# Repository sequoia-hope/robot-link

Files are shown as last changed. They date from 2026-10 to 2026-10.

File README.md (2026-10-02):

# robot-link (comms)

### ▶ [Project page: schematic, PCB and 3D viewer](https://sequoia-hope.github.io/robot-link/)

A dev board for ST's 60 GHz contactless link: an **RP2350A** beside an
**ST60A3H1** (antenna in the package), 28 × 63 mm, six layers. Two boards
face each other a few centimetres apart and tunnel UART, GPIO, I²C or
USB 2.0 between them. The same board is either end. On the back there is a
connector for an **OV2640** camera module.

**Status: rev B captured, placed and routed. 100 parts, 83 nets; KiCad's DRC
and ERC report nothing, KiCad's own netlist of the drawn schematic matches
`tools/circuit.py` net for net, every placed part has an LCSC number and
the assembly check passes. Not fabricated, and no firmware yet.**

- **Rev A** (tag `rev-a`): the link board, four layers. Reviewed on
  2026-10-02; what the review found and changed is [below](#review).
- **Rev B**: rev A plus the [camera](#the-camera-rev-b), and six layers.

- `index.html` — status page with the board viewer (SCH, PCB, 3D); published
  from `main` at <https://sequoia-hope.github.io/robot-link/> by GitHub Pages, and
  served locally with `proj up comms`, address from `proj url comms`
- `hardware/comms/` — the KiCad project
- `tools/` — everything is generated; see below

## Why the ST60A3H1 and not the ST60A2G0

The board was asked for with the ST60A2G0. That part's ball map, pin
functions and the 60 GHz antenna and PCB-transition design are only in ST's
NDA package; the public data brief has the package outline and a block
diagram. The ST60A3H1 is the same family with a public data sheet
(DS14598) and the antenna in the package, so there is no 60 GHz copper to
design. It gives up speed: 480 Mbit/s (eUSB2) against the A2's 6.25 Gbit/s
SLVS.

## What is on it

| | |
|---|---|
| MCU | RP2350A with its core regulator, crystal, flash and decoupling as Raspberry Pi's minimal design (RP-006440) has them — the copper round the chip is read out of that board file |
| Link | ST60A3H1 on a grounded island with a copper-free ring round it, 3.5 mm in from the board edge, as on ST's X-NUCLEO-60K1A1 (B2379A) |
| Translator | TXS0108E, 1.8 V ↔ 3.3 V, on the configuration bus, the four tunnel pins, MODE_INT and LINK_STATUS; off until the RP2350 enables it. 4k7 pull-ups on the 1.8 V side of the configuration bus and of the tunnelled SCL/SDA |
| USB | PTN3222 eUSB2 repeater and two TS3USB221A switches: connector, RP2350 and the 60 GHz link, any two joined |
| Power | USB-C 5 V → AMS1117-3.3 → TLV75518P (1.8 V, off until GPIO11 goes high; dropping it is the ST60's power-on reset) |
| I/O | two 1 × 16 headers 0.9 in apart, SWD on JST-SH, BOOTSEL, RUN, power / link / user LEDs |
| Camera | on the back: a 24-way flex connector for the common OV2640 module (the ESP32-CAM's), its 2.8 V and 1.3 V regulators, pull-ups. Its signals are header GPIO |
| Mechanical | four M2.5 holes mirrored about the antenna's axis: a second board turned over on standoffs puts the two antennas on one line. Three fiducials |

GPIO map (`tools/circuit.py` has the reasons): 0–7 right-hand header · 8/9 USB
path selects · 10 RF_EN · 11 1.8 V enable · 12/13 tunnelled SDA/SCL (I2C0) ·
14 LINK_STATUS · 15 MODE_INT · 16/17 tunnelled TXD/RXD (UART0) · 18/19
configuration bus (I2C1; ST60A3H1 at 0x60, PTN3222 at 0x43) · 20 translator
enable · 21–24, 26–29 left-hand header · 25 LED.

## The camera (rev B)

For the bare OV2640 module with a 24-way, 0.5 mm flex tail: the one on the
ESP32-CAM. The connector (Hirose FH12-24S-0.5SH, bottom contact) is on the
**back** of the board. The tail goes in from the USB end with its contacts
toward the board; the module then lies on the back, behind the RP2350, with
its lens looking away from the board. That is the side away from the board
the 60 GHz link faces.

| Camera | GPIO | |
|---|---|---|
| Y2 – Y9 (data) | 0 – 7 | in order: one PIO `in pins, 8` |
| VSYNC | 21 | |
| SIOD / SIOC | 22 / 23 | I2C1, on its second pair of pins (the link's configuration bus is I2C1 on 18/19: move the peripheral, the buses do not share a wire). 4k7 pull-ups |
| PWDN | 24 | 10 k pull-up: the camera sleeps until this is driven low |
| HREF | 26 | |
| XCLK | 27 | from PWM slice 5 B, or PIO: 6 – 24 MHz, so 150 MHz ÷ 8, 10 or 12 (÷ 6 is 25 MHz, too fast). Low drive strength, slow slew: it runs beside PCLK |
| PCLK | 28 | |
| RESET | none | 10 k and 1 µF; the sensor has a software reset (COM7 bit 7), to be used once XCLK is running |

These are header pins, and with no camera plugged in they are nothing else:
26–28 are the ADC pins and have no resistor on them. 22, 23 and 24 keep
their pull-ups.

The sensor's core is on 1.3 V (OmniVision's data sheet from v1.8 on: 1.24 to
1.36 V. The older sheets, and the ESP32-CAM, say 1.2 V), its analogue side
on 2.8 V, its I/O on 3.3 V. The regulators have no enable: a fitted camera
in power-down draws 1 – 2 mA. To wake it: start XCLK, wait 10 ms, drive
PWDN low, reset it over SCCB, then configure.

The order of signals on GPIO 21–28 is not free. The camera's wiring is laid
by hand on the back, from the headers' own through-hole pads to the
connector, in one layer with nothing crossing, and only this order allows
that (`gen_board.camera_copper`).

**Checked, not tested:** which end of the connector is pin 1. The module
makers number the tail one way and the ESP32-CAM's schematic the other. The
board's pads were checked signal by signal, twice and independently, against
two module makers' mechanical drawings and Hirose's data sheet (contacts on
the face away from the lens; with the tail toward you and the contacts up,
NC and AGND on the right, Y0 and Y1 on the left). Check the module in hand
against that before plugging it in: a variant with a mirrored tail would be
the one way this is wrong.

An independent review of the camera addition (2026-10-02) confirmed the pin
order and found four things, all changed: the core supply (was 1.2 V), 100 nF
on each rail at the connector and wider supply tracks, more room round XCLK
where the wiring allows it, and the module's outline on the silkscreen, which
was 2.7 mm out. Left as they are: XCLK still runs 0.125 mm from PCLK and HREF
under the connector (the pads' order puts it between them); DOVDD is 3.3 V,
the data sheet's maximum, as on the ESP32-CAM.

With the headers soldered pins-down straight into a carrier board there is
about 2.5 mm under the board, and the module is 5.5 mm tall: it needs
sockets, or the headers the other way up.

## Board rules

Six layers, JLCPCB's JLC06161H-7628 stack: F.Cu parts and signals, In1 solid
ground, In2 and In3 routed signals, In4 supplies (+3V3, with +1V8 over the
link section), B.Cu signals, the camera's wiring and its parts. The outer
prepreg is the same 0.21 mm as JLCPCB's four-layer stack, so the antenna's
ground and the USB pairs sit as they did on rev A. Routed signals are
0.125 mm track and clearance (JLCPCB's floor is 0.09), and so are the ST60's
ball escapes. The USB pairs on the back are 0.28 mm wide and 0.16 mm apart.
Vias 0.46 / 0.2 mm, all through.

Why six: rev A routed on four. With the camera's wiring and parts on the
back, the same board on four layers left two to seven nets open in each of
three attempts, the nets at the RP2350's pins that had been marginal on
rev A. On six it closes in one or two.

## Ordering and using it

- **JLCPCB Standard PCBA, not Economic**: the ST60A3H1 is a 0.4 mm BGA, and
  Economic stops at 0.5 mm. Standard wants edge rails (JLCPCB adds them) and
  fiducials (three are on the board). Ask for a 0.10 mm stencil.
- Fifteen parts are on the back (the camera's): assembly is two-sided. To
  build the board without the camera, leave the back unassembled; nothing
  on the front depends on it.
- Green solder mask: the ST60's mask openings are 0.30 mm on 0.25 mm lands,
  which leaves 0.10 mm webs between balls, JLCPCB's minimum for green.
- Four vias sit in the gap in the ST60's ball field, tented. Plugged vias
  are the safer order.
- Fit the headers **pins down**, and use **nylon** standoffs at the antenna
  end (H1, H2): metal 11 mm from the patch is inside its beam.
- Firmware: +1V8 is off at reset. Raise GPIO11, wait 2.25 ms, then enable
  the translator (GPIO20) and RF_EN (GPIO10). Before dropping +1V8, take
  both low first. The PTN3222 is held in reset whenever the RF link is down,
  so anything written to it has to be written again after each link-up.
- VBUS on the headers is the USB-C connector's VBUS, direct: it is an
  output. Do not feed 5 V into it with a host plugged in.
- Pull-ups added on J2/J3 (the 3.3 V side of the translator) should be
  8k2 or more.

## The tools

```
python3 tools/circuit.py        # the netlist, as data, and its checks
python3 tools/symbols.py        # hardware/parts/comms.kicad_sym
python3 tools/footprints.py     # hardware/parts/comms.pretty
python3 tools/placement.py      # where every part sits, and its checks
python3 tools/gen_board.py --force   # project, schematic and the unrouted board (DISCARDS routing)
python3 tools/route.py          # freerouting on a stripped copy, results copied back, stitching
python3 tools/schdraw.py --check     # KiCad's netlist of the schematic against circuit.py
python3 tools/assembly.py       # IPC-2581, the pin-1 answers beside it, boardvis's check
python3 tools/regen.py          # every check, then the viewer and the status line on index.html
```

`gen_board.py` lays the copper that is decided rather than routed: Raspberry
Pi's tracks and pours round the RP2350, the ST60's ball field and antenna
ground (ST's own via pattern, hole for hole where it fits), the 480 Mbit/s
USB pair, a via beside every pad on a plane net,
the camera's wiring.
`route.py` hands the remaining ~70 signals to freerouting 2.2.4
(`~/Software/magnet/route`); it is not deterministic, so it makes several
attempts and keeps the first that closes everything.

## Review

Two independent passes on 2026-10-02, one over the schematic against the
data sheets and one over the layout against JLCPCB's limits and ST's
reference board. Neither found anything that would stop the board working.
What they found, and what was done:

| Finding | Done |
|---|---|
| The antenna ground was a quarter of ST's: 13 vias in the island and 15 round it, where B2379A has 53 and 56; the signals crossed the island on a diagonal | The ball field is laid as ST lays it: nine signals straight out through one side of the ring, the supply along the top of them. ST's vias are taken from its drill file: 33 fit in the island and 45 round it |
| +1V8 fall time marginal against the ST60's 1 ms limit (3.3 µF on a 120 Ω discharge) | 1.8 µF on the rail; the regulator's enable is pulled down, so the rail only rises with 3V3 settled |
| MODE_INT strap undefined if +1V8 is cycled with the translator on | 4k7 to ground on MODE_INT |
| No pull-ups on the I²C lines; ST60 and PTN3222 both want external ones | 4k7 to +1V8 on the configuration bus and on GPIO[2]/[3] |
| USB pair geometry computed at 100 Ω; it crossed two plane splits and ran 2.4 mm over no plane | 0.28 / 0.16 mm (89 Ω by the reviewer's field solver); +1V8 plane redrawn so the pair has +3V3 under it throughout; its copper now 0.8 mm from the board edge, not 0.57 |
| Solder-mask webs between balls 0.075 mm | Mask opening 0.30 mm, webs 0.10 mm |
| Silkscreen under JLCPCB's 1.0 mm / 0.15 mm | Back labels 1.0 mm, front 0.8 mm (what fits a 2.54 mm pitch), all lines 0.15 mm |
| VBUS ran under the USB-C shell | Joined on the back |
| LEDs near dark at 1 kΩ (Vf 3.1 V) | 220 Ω |
| No fiducials | Three |
| Four 3V3 capacitors at the RP2350 fed only through the ring under the chip; one via pair into the plane at the regulator | A via beside each of the four capacitors; five more at the regulator's tab |

Left as it is, knowingly:

- **TXS0108E on the I²C lines.** The reviewer would rather have a pass-FET
  translator with no edge accelerators there: the ST60 has no glitch filter
  on CFG_SCL. ST's own board uses an auto-direction part (ST2378E) on the
  same lines; that part's data sheet was not read. If the configuration bus
  misbehaves with wiring on J2, this is the first place to look.
- **AMS1117 with ceramic output capacitors**, as Raspberry Pi's reference has
  an 1117: outside what the AMS data sheet characterises (22 µF tantalum).
  It needs about 1 V of headroom, so VBUS has to stay above 4.35 V.
- **The crystal** is servodrive's 2520 (CL 20 pF) with 27 pF, where Raspberry
  Pi specifies an ABM8-272 with 15 pF and says any change needs testing.
- **USB pair skew**: D− is 1.1 mm longer than D+ between the connector and
  the first switch (its two pads are joined under the shell). The long run
  to the repeater is matched to 0.05 mm.
- **The ground guard round the crystal** in the reference was not copied;
  three signals pass within 0.13 mm of the crystal nets.

## Not yet verified

- Nothing has been built. The ST60A3H1 land and the PTN3222 land are drawn
  from the manufacturers' drawings, not from a part in hand.
- The antenna island copies ST's dimensions and vias off their Gerbers; the
  pattern on this board has not been simulated or measured, and it has
  fewer vias than ST's where this board's tracks are in the way.
- The 89 Ω figure for the USB pairs is one reviewer's solver, checked
  against a textbook formula only. Confirm with JLCPCB's calculator.
- JLCPCB capability figures were read off their site on 2026-10-02 through
  a summarising tool, not from the raw pages. Check them at order time.
- Several pin-1 answers in the assembly sidecar are package convention,
  not read off that part's data sheet; the sidecar says which.
- Rev B's camera connector: see "Checked, not tested" above. The camera's
  wiring runs 15 to 40 mm on the back over the supply plane; nothing about
  its signal integrity at a 20 MHz pixel clock has been measured.
- The 2.8 V regulator is listed as UMW's XC6206; its data sheet numbers the
  pins oddly, and the reviewer read it as the same physical order as Torex's.

## Next

Firmware: the link's bring-up sequence, a PIO capture for the camera. Then
a first build.

CERN-OHL-P.

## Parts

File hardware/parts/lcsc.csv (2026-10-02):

# LCSC part numbers the project has chosen | keyed by value and footprint as
# the board file writes them; pcbview joins this into the viewer's part pane.
# The C-number is the same at LCSC and JLCPCB.
#
# Every part the assembler places has a row. Rows marked "as servodrive" are
# that project's choices for the same value and footprint; the rest were
# looked up in JLCPCB's parts library on 2026-10-02 (model | package | stock).
# The mounting holes have no part.
value | footprint | lcsc | mpn | note
RP2350A | RP2350-QFN-60-1EP_7x7_P0.4mm_EP3.4x3.4mm_ThermalVias | C42411118 | RP2350A | as servodrive
3u3 | L_pol_2016 | C42411119 | AOTA-B201610S3R3-101-T | as servodrive
4u7 | C_0402_1005Metric_small_pads | C23733 | CL05A475MP5NRNC | as servodrive
4u7 | C_0402_1005Metric | C23733 | CL05A475MP5NRNC | as servodrive
33R | R_0402_1005Metric | C25105 | 0402WGF330JTCE | as servodrive
100n | C_0402_1005Metric | C1525 | CL05B104KO5NNNC | as servodrive
27R | R_0402_1005Metric | C25100 | 0402WGF270JTCE | as servodrive
12MHz | Crystal_SMD_2520-4Pin_2.5x2.0mm | C284156 | TXM12M0004252LBCEO00T | as servodrive
1k | R_0402_1005Metric | C11702 | 0402WGF1001TCE | as servodrive
27p | C_0402_1005Metric | C1557 | 0402CG270J500NT | as servodrive
W25Q16JVUXIQ | Winbond_USON-8-1EP_3x2mm_P0.5mm_EP0.2x1.6mm | C2843335 | W25Q16JVUXIQ | as servodrive
BOOTSEL | SW_SPST_B3U-1000P | C231329 | B3U-1000P | as servodrive
RUN | SW_SPST_B3U-1000P | C231329 | B3U-1000P
SWD | JST_SH_SM03B-SRSS-TB_1x03-1MP_P1.00mm_Horizontal | C2845362 | HC-1.0-3PWT | SH-compatible 3-way, in stock by the reel; JST's own SM03B-SRSS-TB is C160403, 22 in stock that day
blue | LED_0603_1608Metric | C2288 | KT-0603B | Vf 3.1 V at 5 mA: on 3V3 through 1k it runs well under 1 mA, dim on purpose
LEFT | PinHeader_1x16_P2.54mm_Vertical | C22465876 | PZ254V-11-16P | through-hole; fit by hand, or leave off the assembly order
RIGHT | PinHeader_1x16_P2.54mm_Vertical | C22465876 | PZ254V-11-16P | through-hole; fit by hand, or leave off the assembly order
ST60A3H1 | ST_VFBGA-23_AiP_2.95x4.07mm_P0.4mm | C49438993 | ST60A3H1C1CCEPY3 | 36 in stock that day; 0.4 mm VFBGA, antenna in package
0R | R_0402_1005Metric | C17168 | 0402WGF0000TCE | basic
1u | C_0402_1005Metric | C52923 | CL05A105KA5NQNC | as servodrive
1k5 | R_0402_1005Metric | C25867 | 0402WGF1501TCE | basic
1k8 | R_0402_1005Metric | C25871 | 0402WGF1801TCE
TXS0108E | TSSOP-20_4.4x6.5mm_P0.65mm | C17206 | TXS0108EPWR
4k7 | R_0402_1005Metric | C25900 | 0402WGF4701TCE | as servodrive
PTN3222GM | NXP_XQFN-12_1.75x2.2mm_P0.4mm | C5364806 | PTN3222GMJ | 359 in stock that day
100p | C_0402_1005Metric | C1546 | 0402CG101J500NT | basic, C0G
MMBT3904 | SOT-23 | C20526 | MMBT3904 | basic
10k | R_0402_1005Metric | C25744 | 0402WGF1002TCE | as servodrive
green | LED_0603_1608Metric | C12624 | KT-0603G | Vf 3.1 V at 5 mA, as the blue one
USB-C | USB_C_Receptacle_HRO_TYPE-C-31-M-12 | C165948 | TYPE-C-31-M-12 | as servodrive
5k1 | R_0402_1005Metric | C25905 | 0402WGF5101TCE | as servodrive
USBLC6-2SC6 | SOT-23-6 | C7519 | USBLC6-2SC6 | as servodrive
TS3USB221A | Texas_UQFN-10_1.5x2mm_P0.5mm | C128396 | TS3USB221ARSER
AMS1117-3.3 | SOT-223-3_TabPin2 | C6186 | AMS1117-3.3 | basic
10u | C_0805_2012Metric | C15850 | CL21A106KAYNNNE | basic, 25 V X5R
TLV75518P | SOT-23-5 | C2877863 | TLV75518PDBVR | the P is the output discharge
220R | R_0402_1005Metric | C25091 | 0402WGF2200TCE | basic; the LEDs' series resistors
470n | C_0402_1005Metric | C92361 | CL05A474KA5NNNC | 25 V X5R
OV2640 | Hirose_FH12-24S-0.5SH_1x24-1MP_P0.50mm_Horizontal | C202112 | FH12-24S-0.5SH(55) | 24-way 0.5 mm flex connector, bottom contact; on the back
XC6206P282MR | SOT-23 | C347374 | XC6206P282MR | 2.8 V LDO (UMW's; Torex's own is C2891263)
ME6216A13M3G | SOT-23 | C236662 | ME6216A13M3G | 1.3 V LDO, 300 mA; SOT23-3 pin order as the XC6206 (1 VSS, 2 VOUT, 3 VIN), read off Microne's data sheet

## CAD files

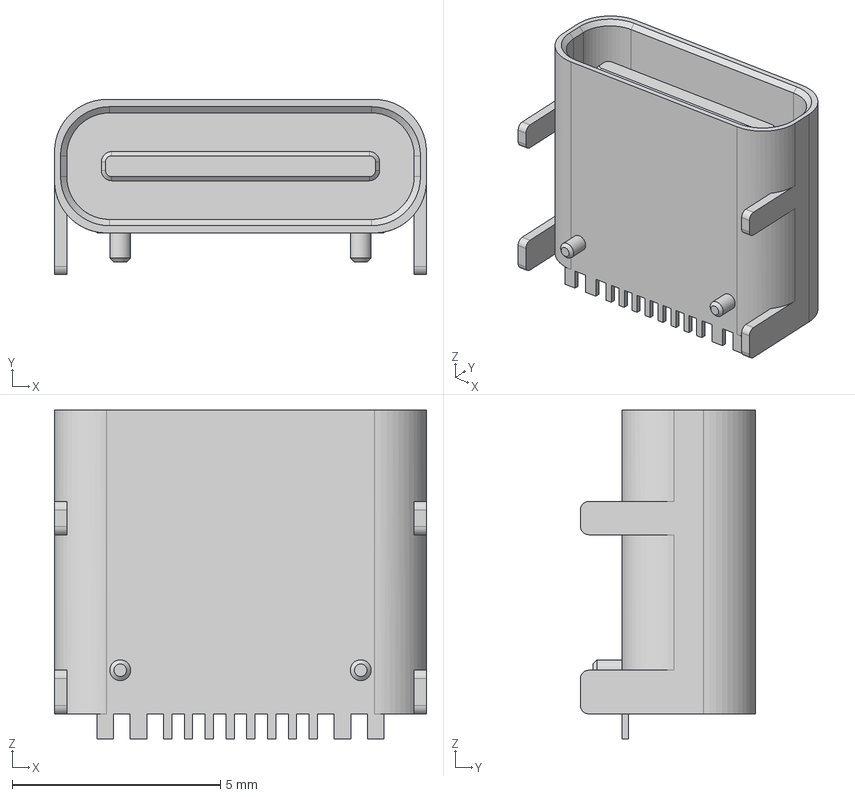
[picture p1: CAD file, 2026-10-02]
hardware/parts/3dmodels/HRO_TYPE-C-31-M-12.step
8.94 x 4.21 x 7.90 mm

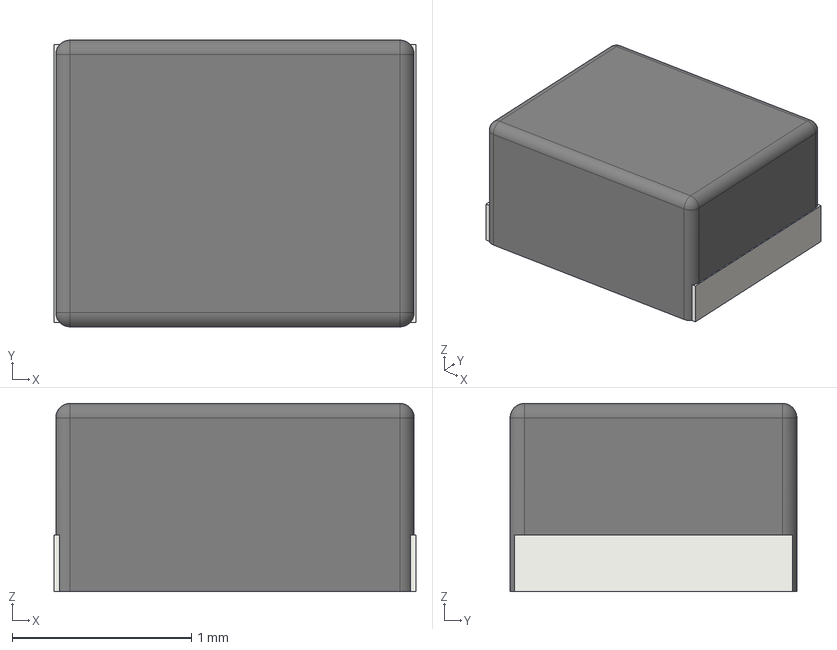
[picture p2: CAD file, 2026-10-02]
hardware/parts/3dmodels/AOTA-B201610SR47MT.STEP
2.02 x 1.60 x 1.05 mm

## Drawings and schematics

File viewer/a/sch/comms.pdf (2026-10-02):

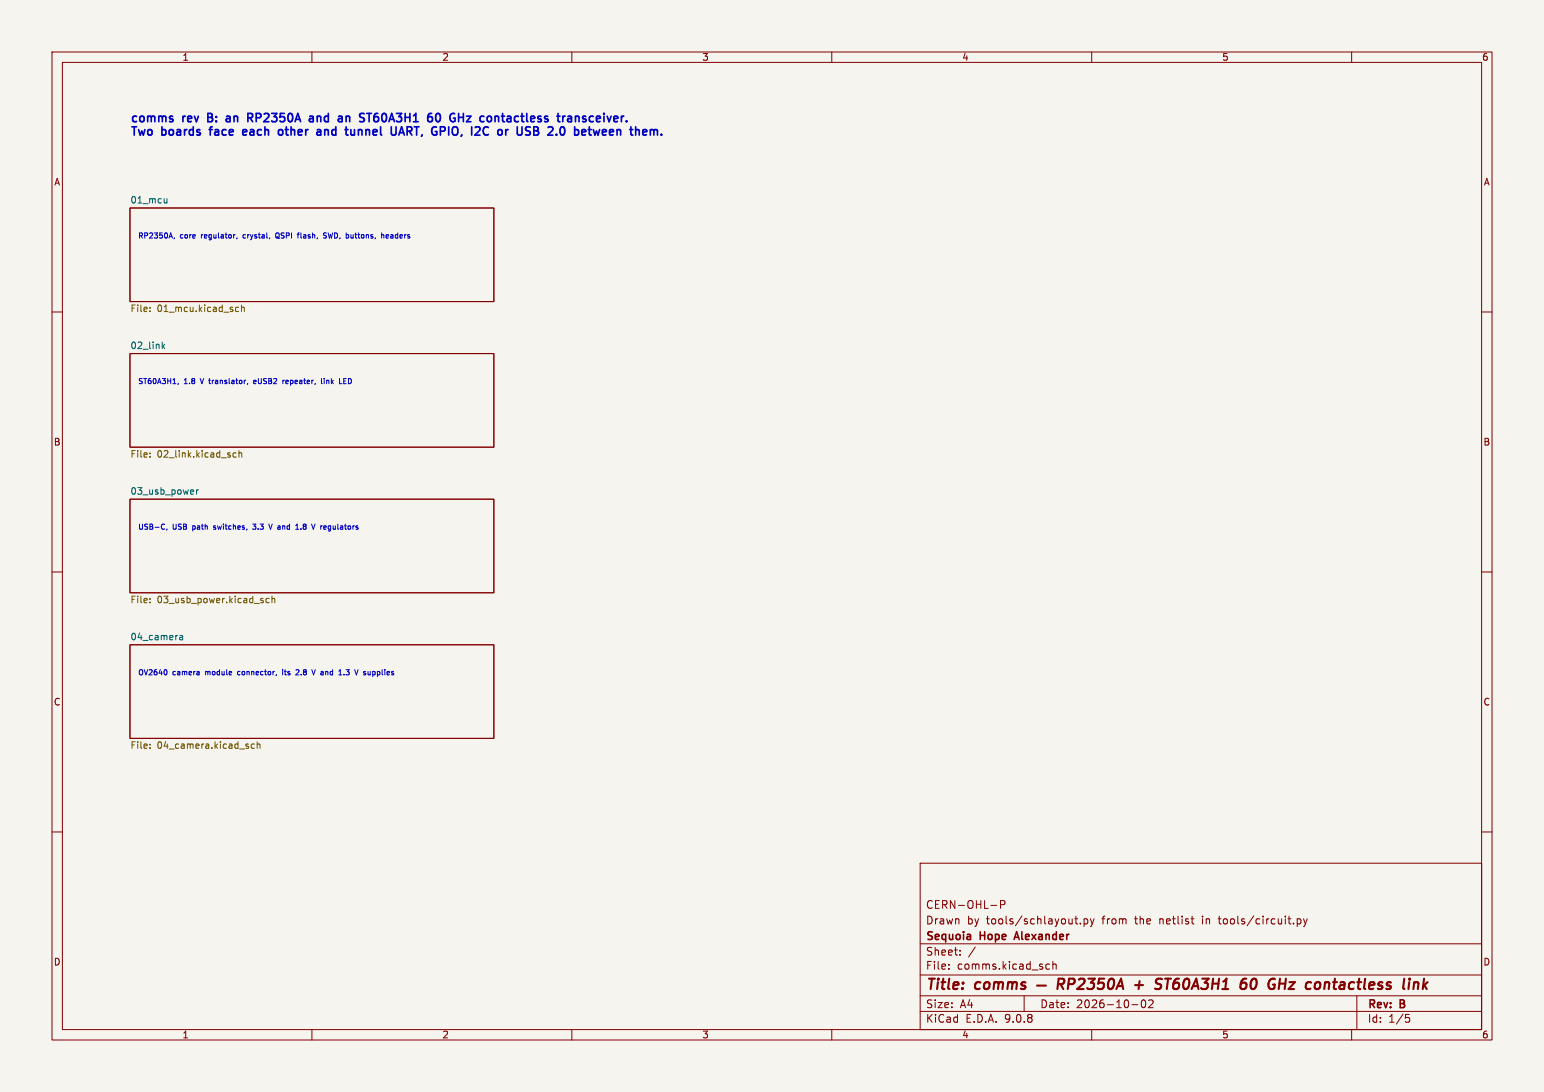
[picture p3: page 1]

Two boards face each other and tunnel UART, GPIO, I2C or USB 2.0 between them.

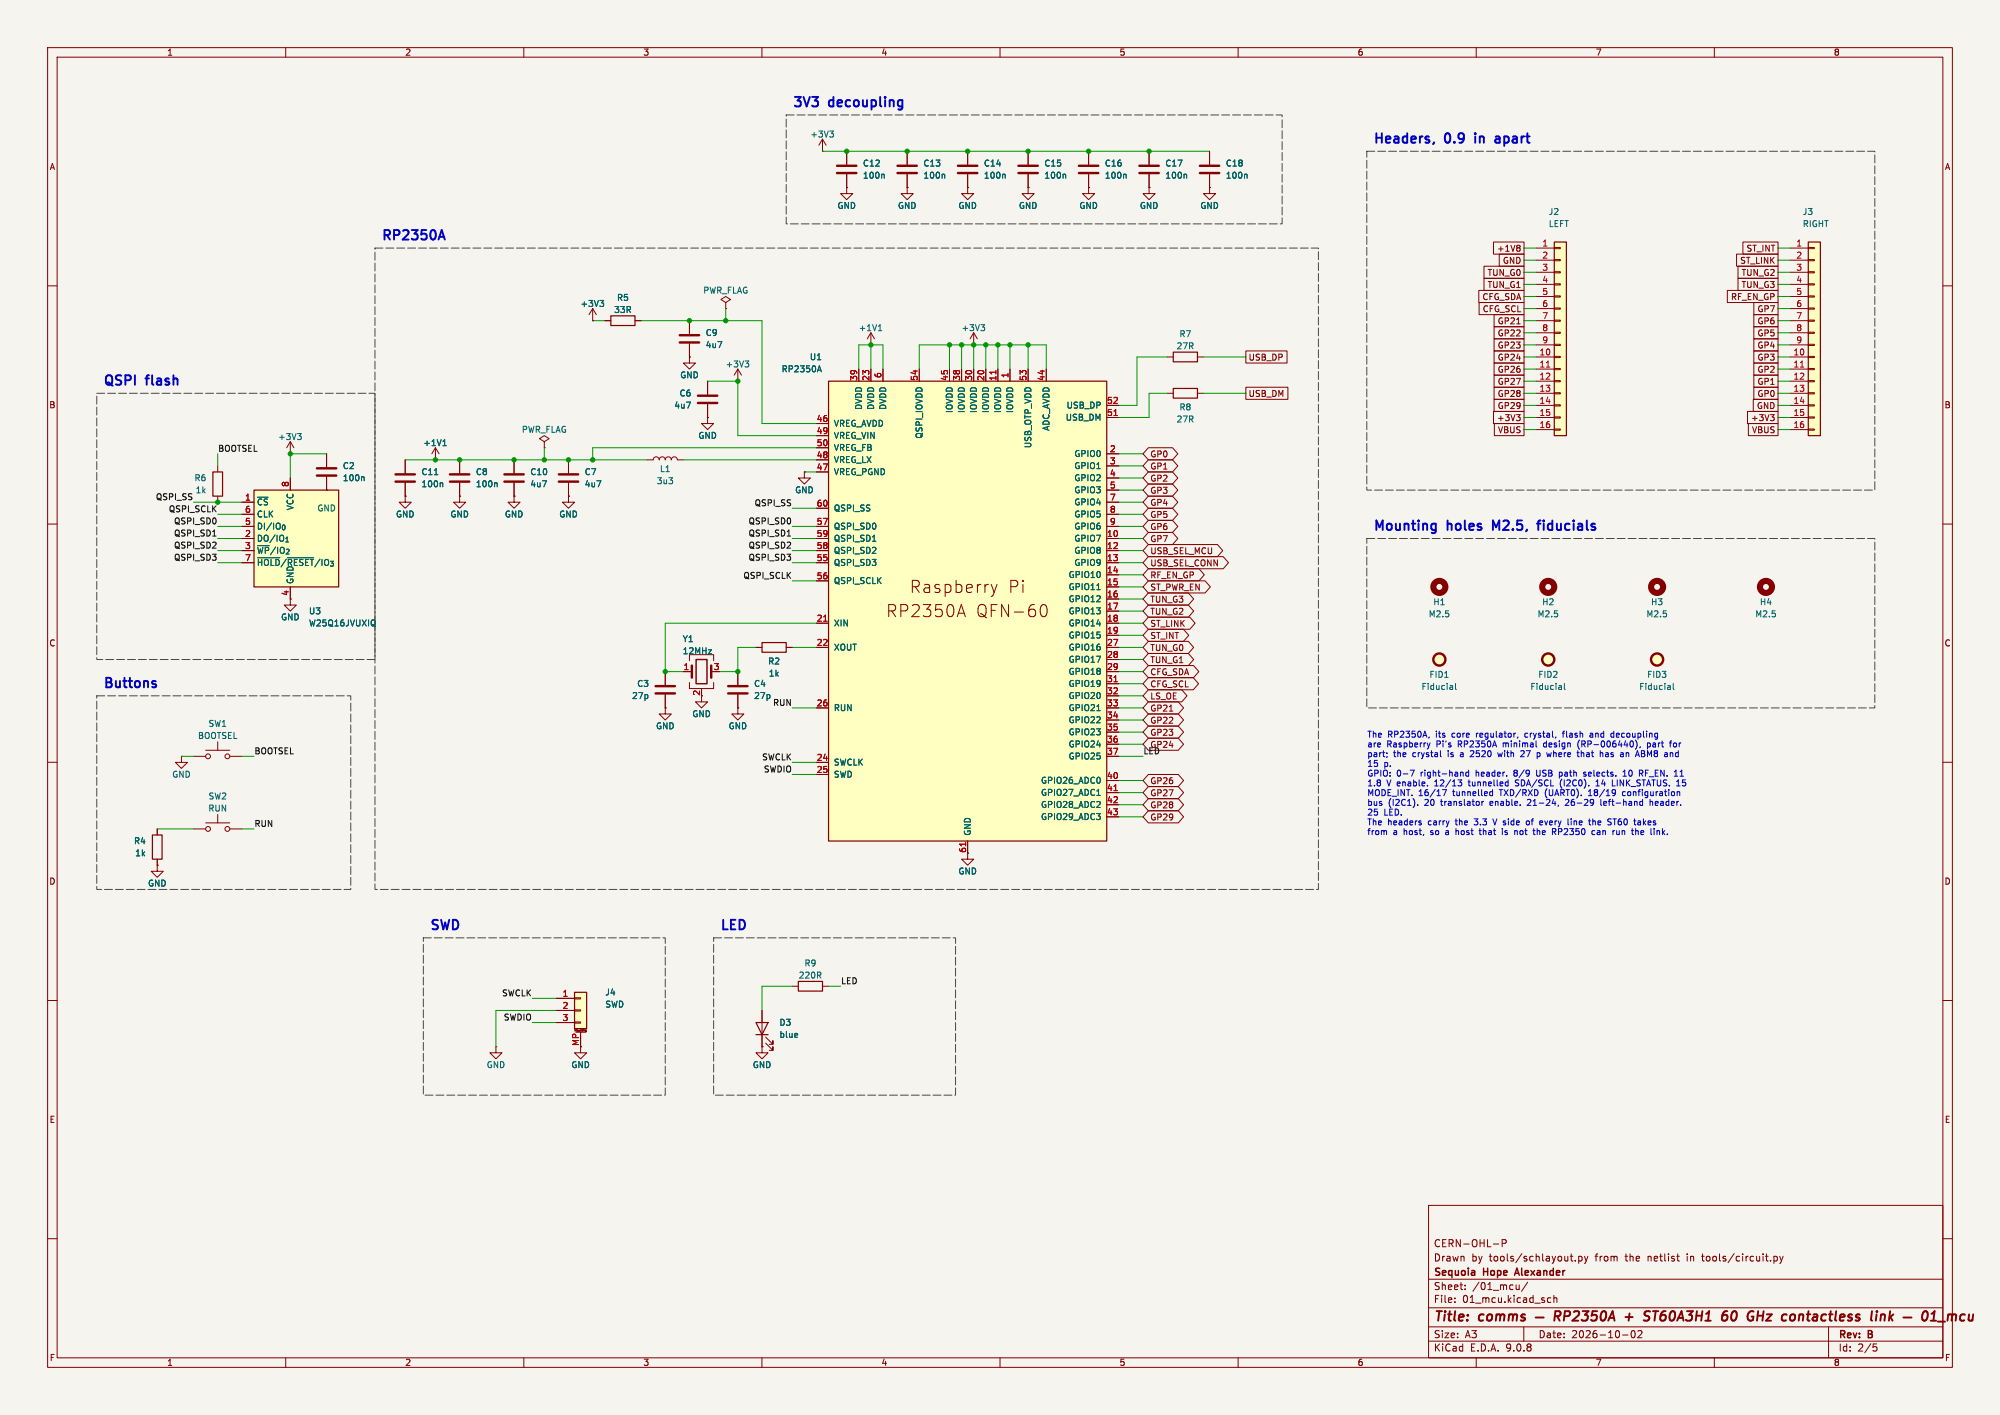
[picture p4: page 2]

6 QSPI_IOVDD 54 IOVDD 45 IOVDD 38 GND 61 IOVDD 30 IOVDD 20 IOVDD 11 IOVDD

from a host, so a host that is not the RP2350 can run the link.

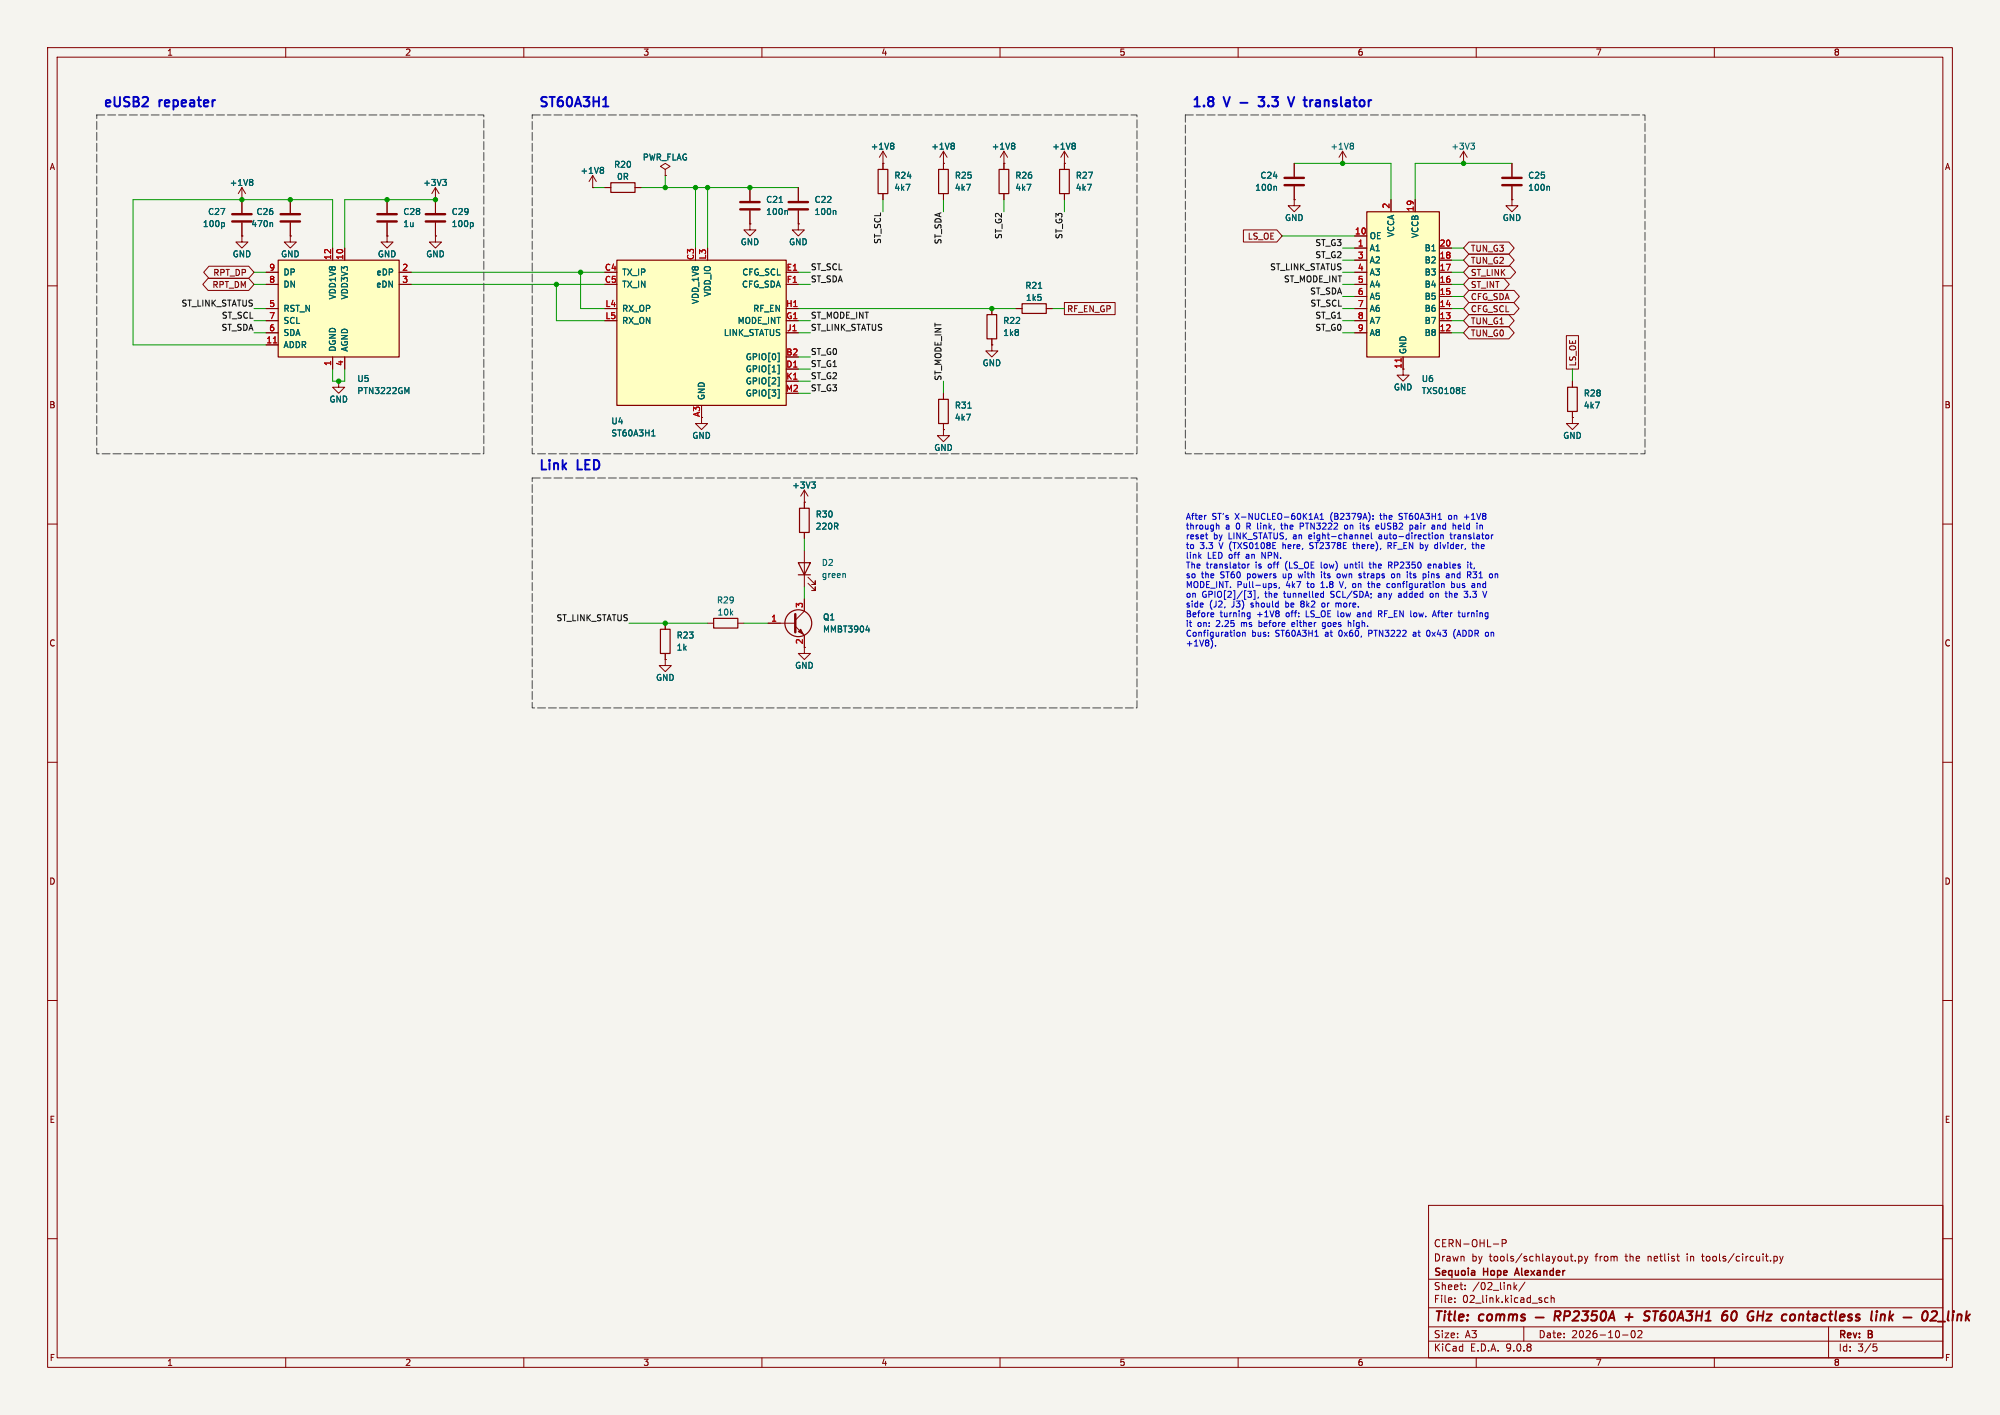
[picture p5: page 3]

LINK_STATUS J1 GPIO[0] B2 GPIO[1] D1 GPIO[2] K1 GPIO[3] M2 C21

2 GND 11 VCCB 19 B1 20 B2 18 B3 17 B4 16 B5 15 B6 14 B7 13 B8 12 U6 TXS0108E GND GND

through a 0 R link, the PTN3222 on its eUSB2 pair and held in
to 3.3 V (TXS0108E here, ST2378E there), RF_EN by divider, the

side (J2, J3) should be 8k2 or more. Before turning +1V8 off: LS_OE low and RF_EN low. After turning

it on: 2.25 ms before either goes high.

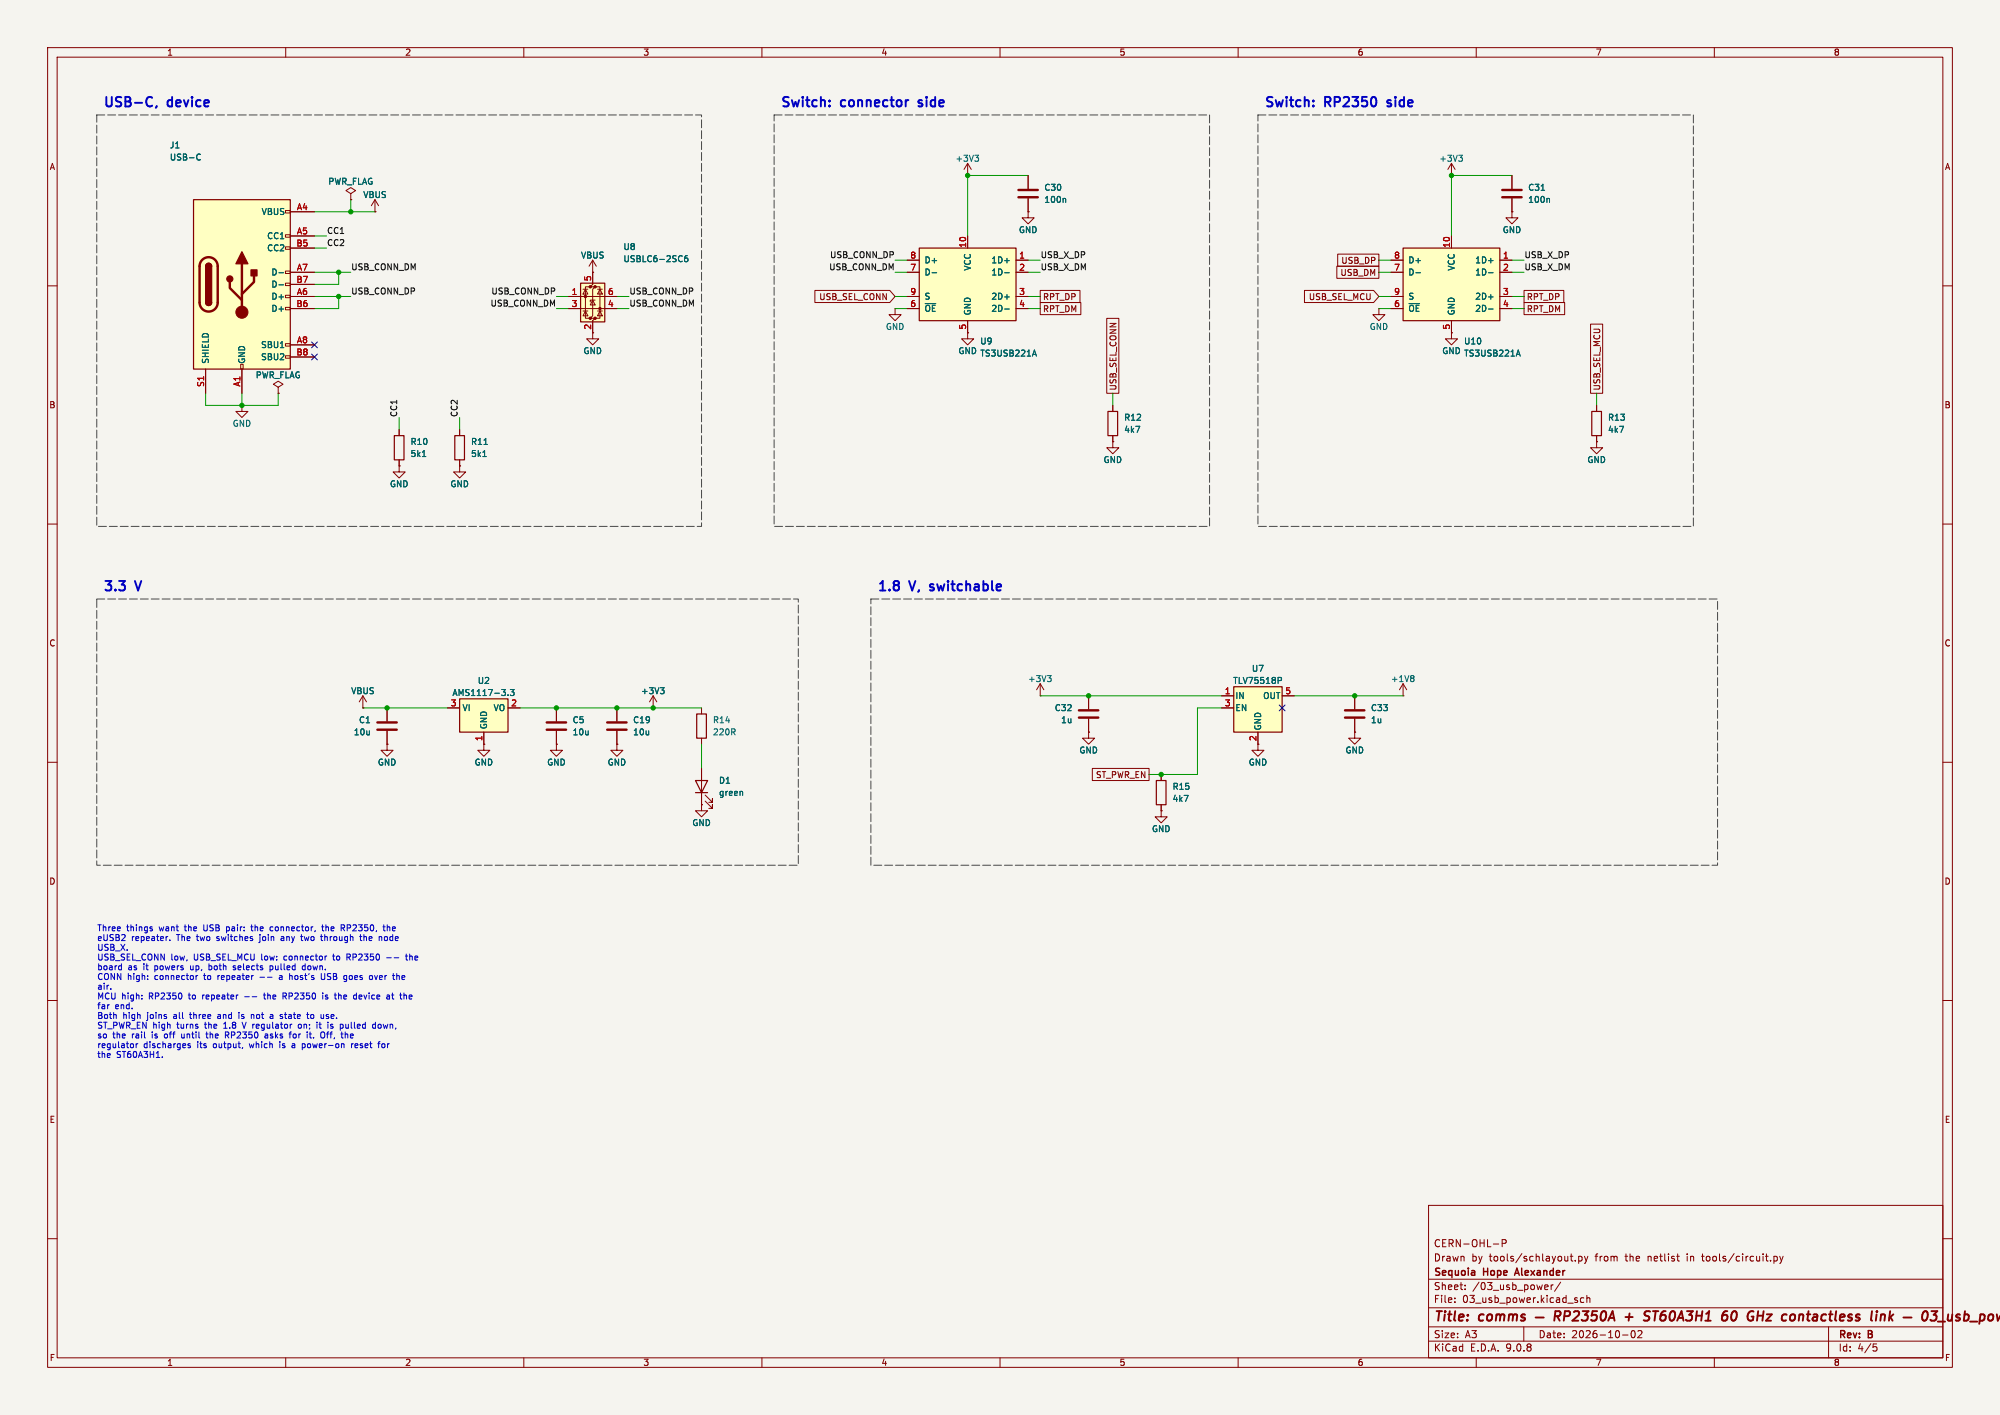
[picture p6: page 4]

2 OUT 5 GND GND GND

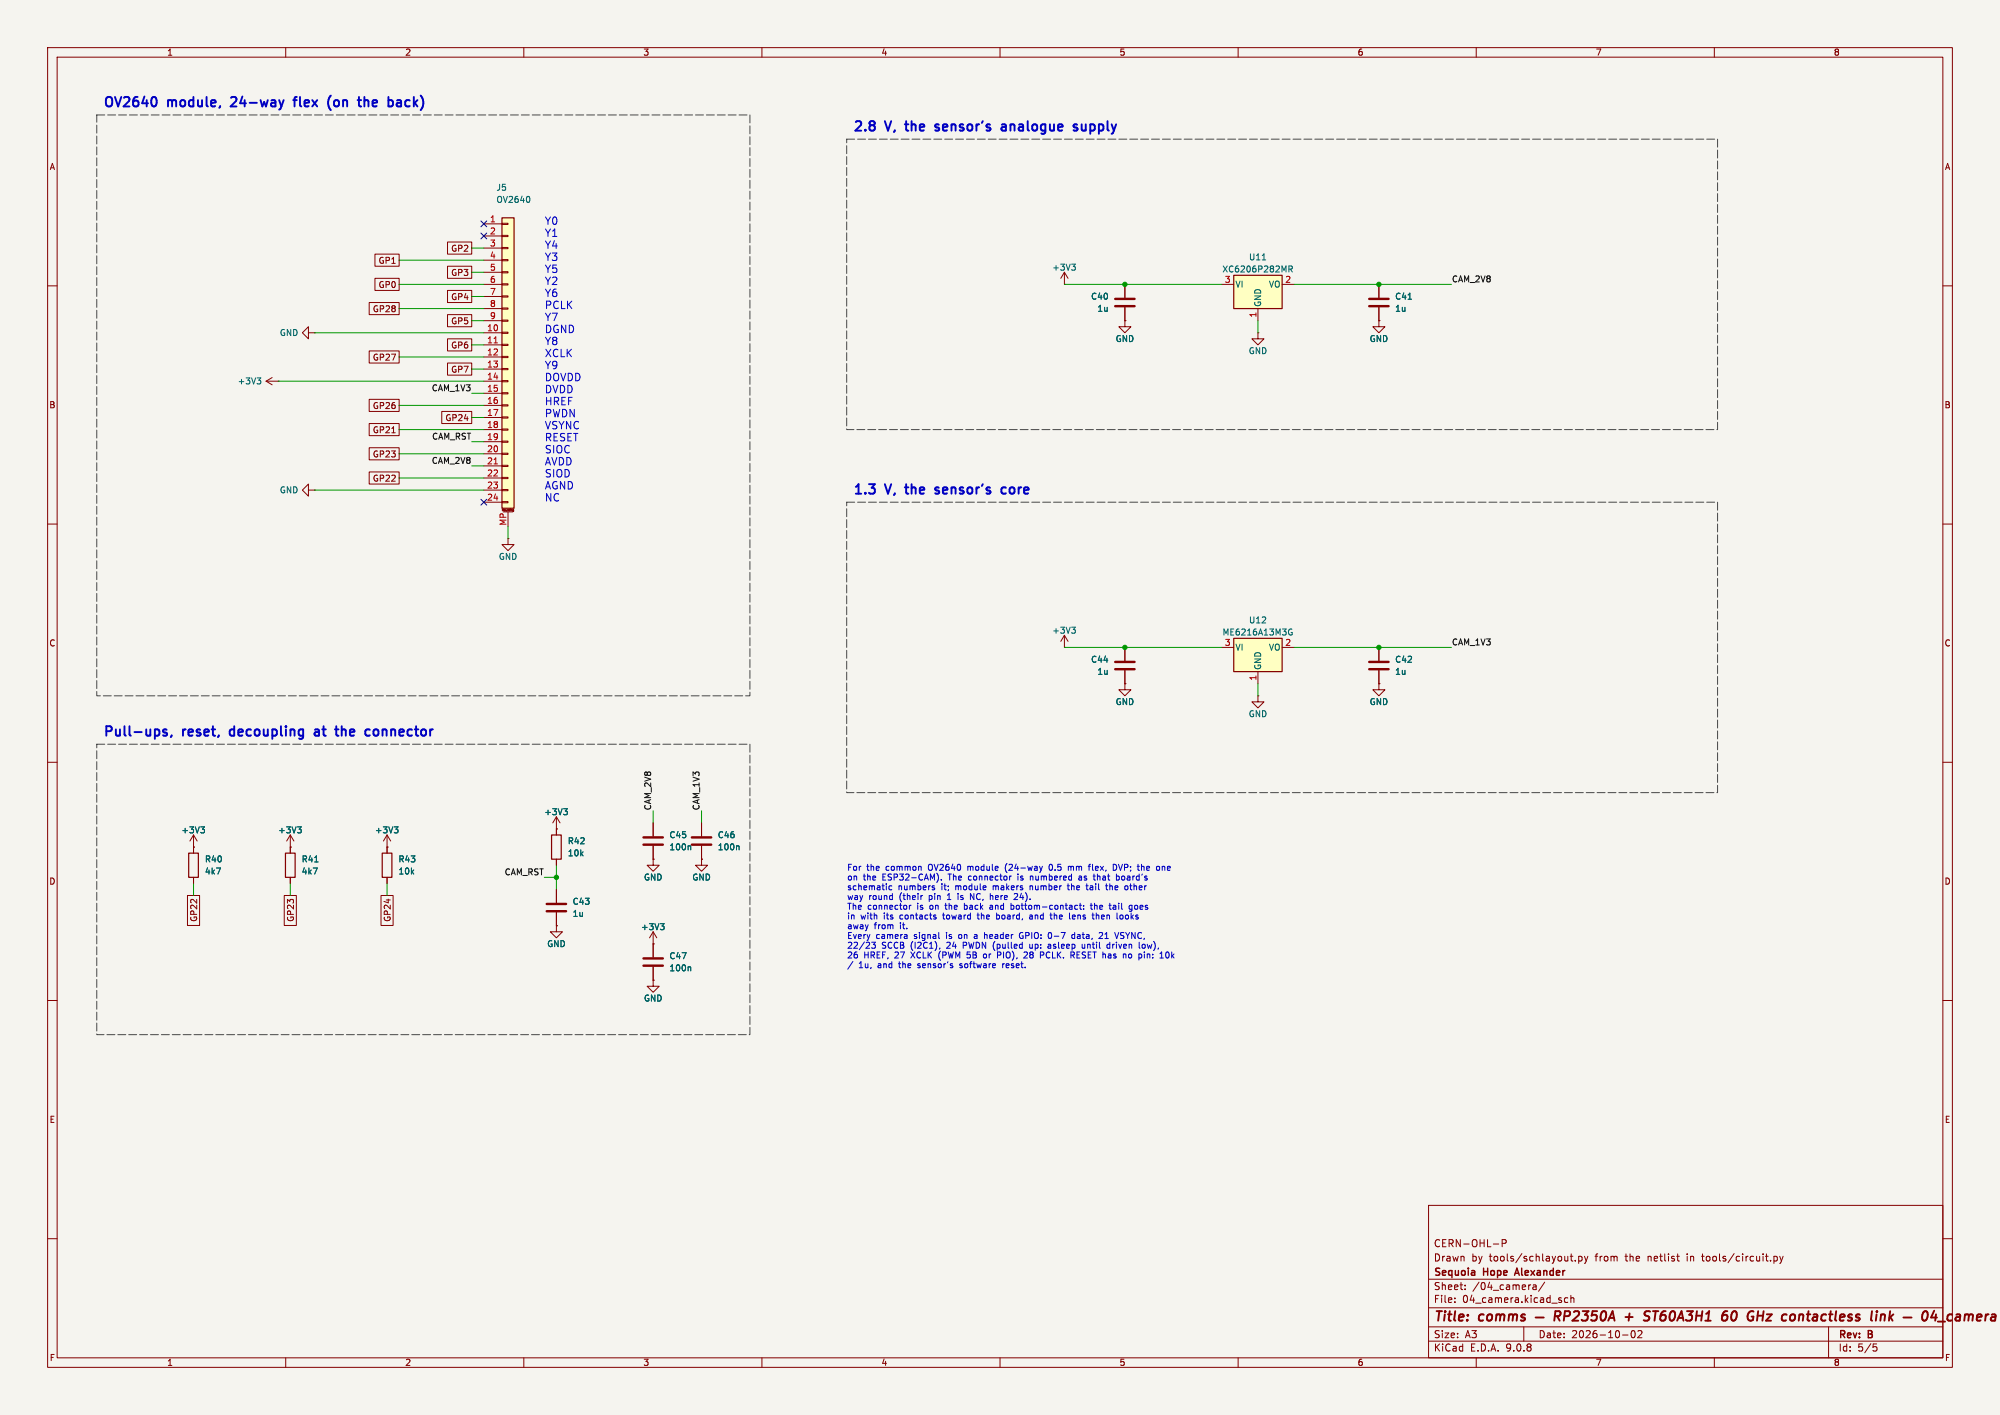
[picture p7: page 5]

2.8 V, the sensor's analogue supply

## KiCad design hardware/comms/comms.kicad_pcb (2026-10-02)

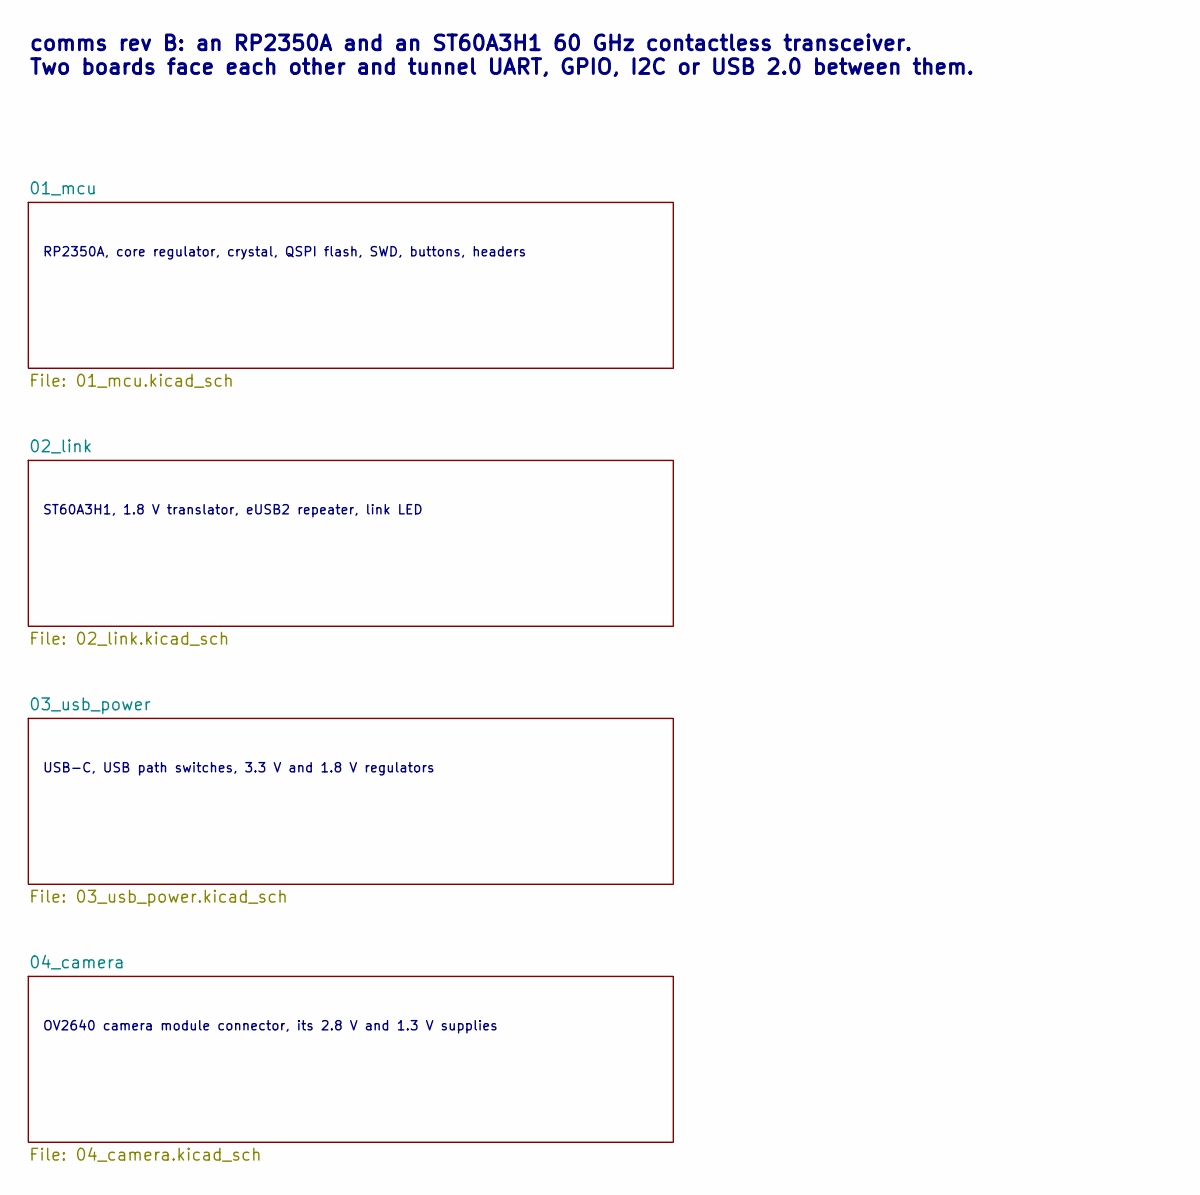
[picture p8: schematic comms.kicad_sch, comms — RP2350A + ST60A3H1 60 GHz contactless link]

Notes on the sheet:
RP2350A, core regulator, crystal, QSPI flash, SWD, buttons, headers
ST60A3H1, 1.8 V translator, eUSB2 repeater, link LED
USB-C, USB path switches, 3.3 V and 1.8 V regulators
OV2640 camera module connector, its 2.8 V and 1.3 V supplies
comms rev B: an RP2350A and an ST60A3H1 60 GHz contactless transceiver. Two boards face each other and tunnel UART, GPIO, I2C or USB 2.0 between them.

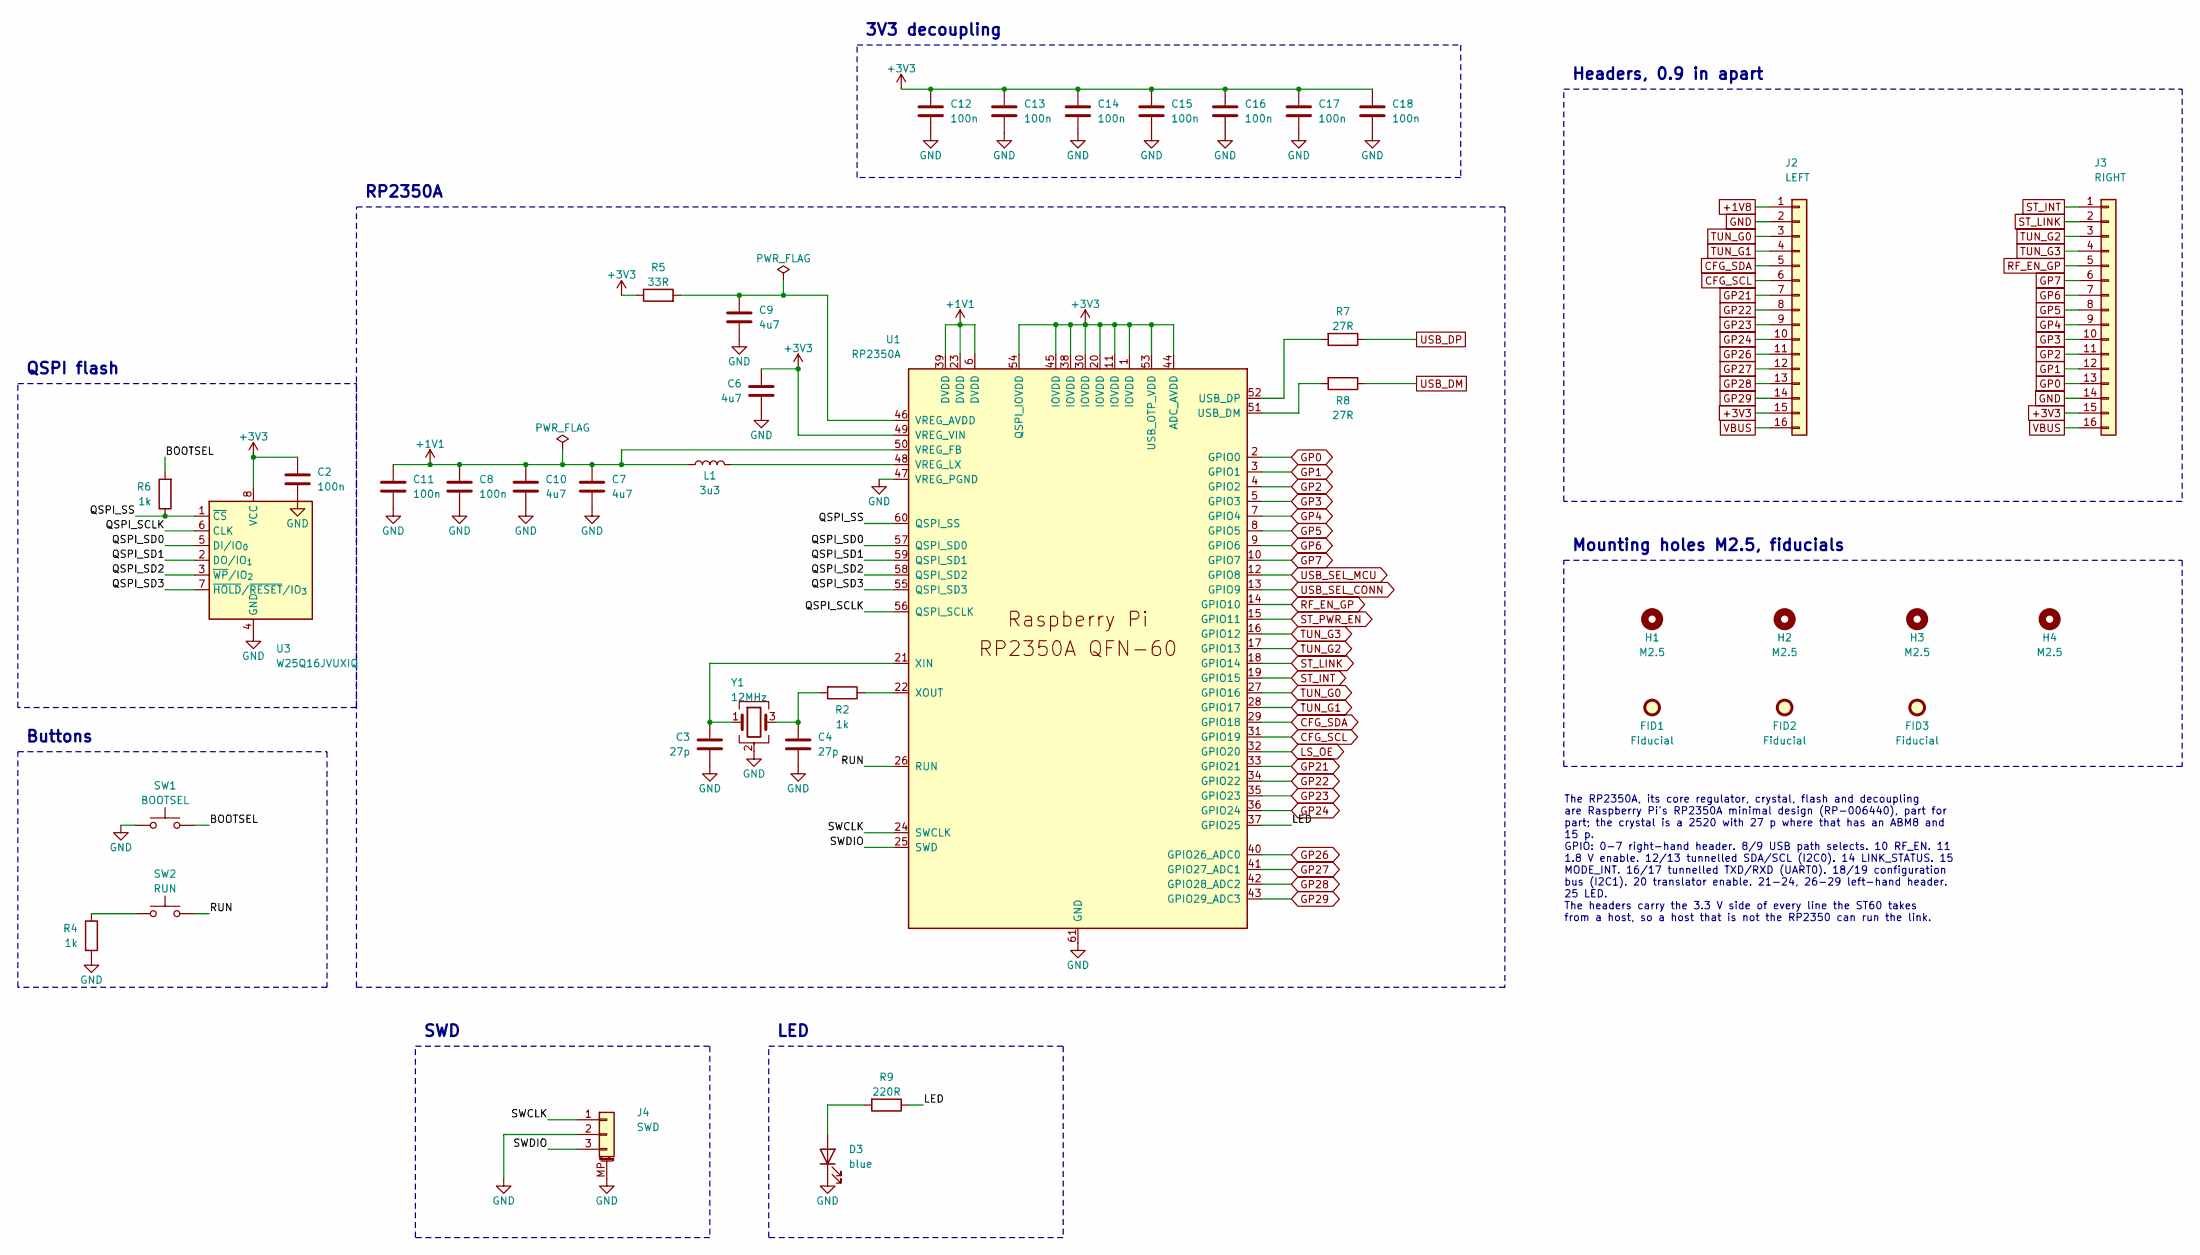
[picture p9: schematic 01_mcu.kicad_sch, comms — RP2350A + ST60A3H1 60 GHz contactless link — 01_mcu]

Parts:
C2, C8, C11, C12, C13, C14, C15, C16, C17, C18: 100n; C_0402_1005Metric
C3, C4: 27p; C_0402_1005Metric
C6, C7: 4u7; C_0402_1005Metric_small_pads
C9, C10: 4u7; C_0402_1005Metric
D3: blue; LED_0603_1608Metric
FID1, FID2, FID3: Fiducial; Fiducial_1mm_Mask2mm
H1, H2, H3, H4: M2.5; MountingHole_2.7mm_M2.5
J2: LEFT; PinHeader_1x16_P2.54mm_Vertical
J3: RIGHT; PinHeader_1x16_P2.54mm_Vertical
J4: SWD; JST_SH_SM03B-SRSS-TB_1x03-1MP_P1.00mm_Horizontal
L1: 3u3; L_pol_2016
R2, R4, R6: 1k; R_0402_1005Metric
R5: 33R; R_0402_1005Metric
R7, R8: 27R; R_0402_1005Metric
R9: 220R; R_0402_1005Metric
SW1: BOOTSEL; SW_SPST_B3U-1000P
SW2: RUN; SW_SPST_B3U-1000P
U1: RP2350A; RP2350-QFN-60-1EP_7x7_P0.4mm_EP3.4x3.4mm_ThermalVias
U3: W25Q16JVUXIQ; Winbond_USON-8-1EP_3x2mm_P0.5mm_EP0.2x1.6mm
Y1: 12MHz; Crystal_SMD_2520-4Pin_2.5x2.0mm

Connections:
+1V1: C7.1, C8.1, C10.1, C11.1, L1.1, U1.6 (DVDD), U1.23 (DVDD), U1.39 (DVDD), U1.50 (VREG_FB)
+1V8: J2.1; also elsewhere on the board
+3V3: C2.1, C6.1, C12.1, C13.1, C14.1, C15.1, C16.1, C17.1, C18.1, J2.15, J3.15, R5.1, U1.1 (IOVDD), U1.11 (IOVDD), U1.20 (IOVDD), U1.30 (IOVDD), U1.38 (IOVDD), U1.44 (ADC_AVDD), U1.45 (IOVDD), U1.49 (VREG_VIN), U1.53 (USB_OTP_VDD), U1.54 (QSPI_IOVDD), U3.8 (VCC); also elsewhere on the board
BOOTSEL: R6.2, SW1.2
CFG_SCL: J2.6, U1.31 (GPIO19); also elsewhere on the board
CFG_SDA: J2.5, U1.29 (GPIO18); also elsewhere on the board
GND: C2.2, C3.2, C4.2, C6.2, C7.2, C8.2, C9.2, C10.2, C11.2, C12.2, C13.2, C14.2, C15.2, C16.2, C17.2, C18.2, D3.1 (K), J2.2, J3.14, J4.2, J4.MP (MountPin), R4.2, SW1.1, U1.47 (VREG_PGND), U1.61 (GND), U3.4 (GND), Y1.2 (G), Y1.4 (G); also elsewhere on the board
GP0: J3.13, U1.2 (GPIO0); also elsewhere on the board
GP1: J3.12, U1.3 (GPIO1); also elsewhere on the board
GP2: J3.11, U1.4 (GPIO2); also elsewhere on the board
GP3: J3.10, U1.5 (GPIO3); also elsewhere on the board
GP4: J3.9, U1.7 (GPIO4); also elsewhere on the board
GP5: J3.8, U1.8 (GPIO5); also elsewhere on the board
GP6: J3.7, U1.9 (GPIO6); also elsewhere on the board
GP7: J3.6, U1.10 (GPIO7); also elsewhere on the board
GP21: J2.7, U1.33 (GPIO21); also elsewhere on the board
GP22: J2.8, U1.34 (GPIO22); also elsewhere on the board
GP23: J2.9, U1.35 (GPIO23); also elsewhere on the board
GP24: J2.10, U1.36 (GPIO24); also elsewhere on the board
GP26: J2.11, U1.40 (GPIO26_ADC0); also elsewhere on the board
GP27: J2.12, U1.41 (GPIO27_ADC1); also elsewhere on the board
GP28: J2.13, U1.42 (GPIO28_ADC2); also elsewhere on the board
GP29: J2.14, U1.43 (GPIO29_ADC3)
LED: R9.1, U1.37 (GPIO25)
LED_A: D3.2 (A), R9.2
LS_OE: U1.32 (GPIO20); also elsewhere on the board
QSPI_SCLK: U1.56 (QSPI_SCLK), U3.6 (CLK)
QSPI_SD0: U1.57 (QSPI_SD0), U3.5 (DI/IO_{0})
QSPI_SD1: U1.59 (QSPI_SD1), U3.2 (DO/IO_{1})
QSPI_SD2: U1.58 (QSPI_SD2), U3.3 (~WP/IO_{2})
QSPI_SD3: U1.55 (QSPI_SD3), U3.7 (~HOLD/~RESET/IO_{3})
QSPI_SS: R6.1, U1.60 (QSPI_SS), U3.1 (~CS)
RF_EN_GP: J3.5, U1.14 (GPIO10); also elsewhere on the board
RUN: SW2.2, U1.26 (RUN)
RUN_SW: R4.1, SW2.1
ST_INT: J3.1, U1.19 (GPIO15); also elsewhere on the board
ST_LINK: J3.2, U1.18 (GPIO14); also elsewhere on the board
ST_PWR_EN: U1.15 (GPIO11); also elsewhere on the board
SWCLK: J4.1, U1.24 (SWCLK)
SWDIO: J4.3, U1.25 (SWD)
TUN_G0: J2.3, U1.27 (GPIO16); also elsewhere on the board
TUN_G1: J2.4, U1.28 (GPIO17); also elsewhere on the board
TUN_G2: J3.3, U1.17 (GPIO13); also elsewhere on the board
TUN_G3: J3.4, U1.16 (GPIO12); also elsewhere on the board
USB_DM: R8.1; also elsewhere on the board
USB_DM_C: R8.2, U1.51 (USB_DM)
USB_DP: R7.1; also elsewhere on the board
USB_DP_C: R7.2, U1.52 (USB_DP)
USB_SEL_CONN: U1.13 (GPIO9); also elsewhere on the board
USB_SEL_MCU: U1.12 (GPIO8); also elsewhere on the board
VBUS: J2.16, J3.16; also elsewhere on the board
VREG_AVDD: C9.1, R5.2, U1.46 (VREG_AVDD)
VREG_LX: L1.2, U1.48 (VREG_LX)
XIN: C3.1, U1.21 (XIN), Y1.1
XOUT: R2.1, U1.22 (XOUT)
XTAL2: C4.1, R2.2, Y1.3

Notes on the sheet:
RP2350A
3V3 decoupling
QSPI flash
Buttons
SWD
LED
Headers, 0.9 in apart
Mounting holes M2.5, fiducials
The RP2350A, its core regulator, crystal, flash and decoupling are Raspberry Pi's RP2350A minimal design (RP-006440), part for part; the crystal is a 2520 with 27 p where that has an ABM8 and 15 p. GPIO: 0-7 right-hand header. 8/9 USB path selects. 10 RF_EN. 11 1.8 V enable. 12/13 tunnelled SDA/SCL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

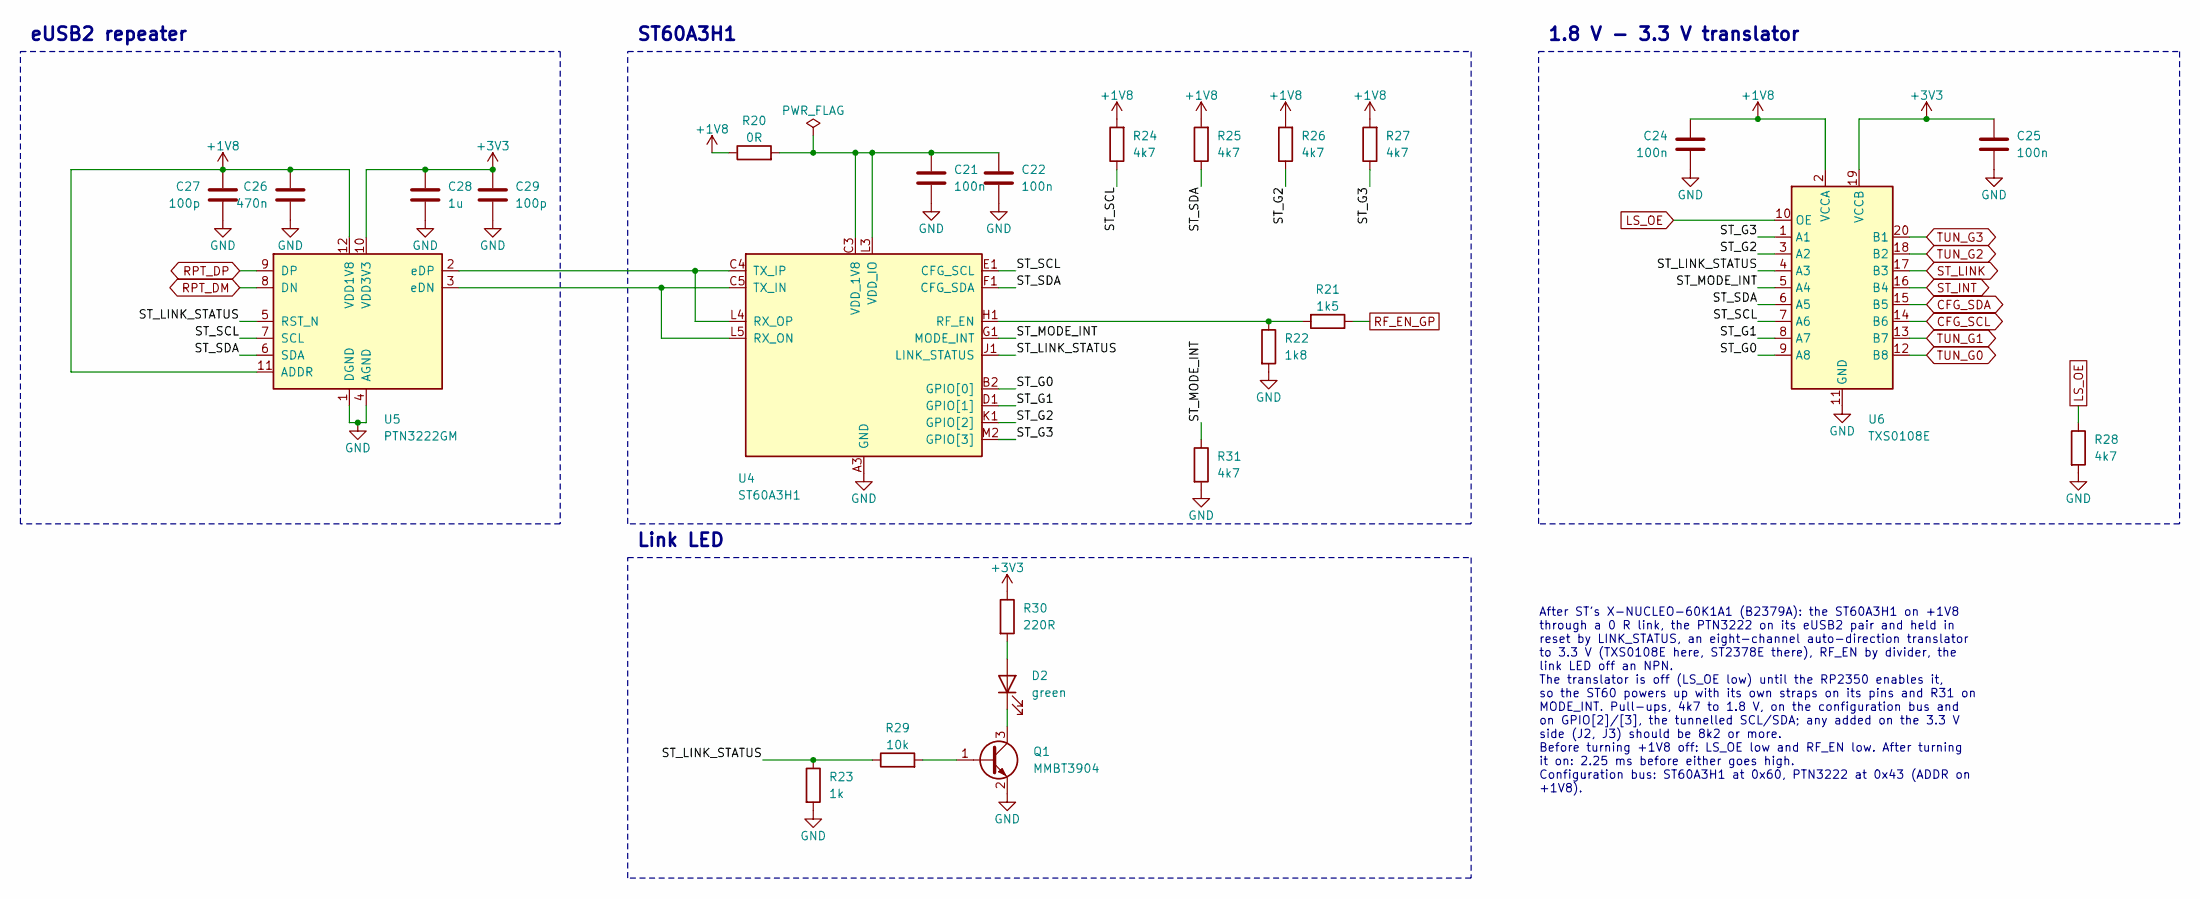
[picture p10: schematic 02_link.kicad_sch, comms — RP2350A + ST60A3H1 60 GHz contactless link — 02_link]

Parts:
C21, C22, C24, C25: 100n; C_0402_1005Metric
C26: 470n; C_0402_1005Metric
C27, C29: 100p; C_0402_1005Metric
C28: 1u; C_0402_1005Metric
D2: green; LED_0603_1608Metric
Q1: MMBT3904; SOT-23
R20: 0R; R_0402_1005Metric
R21: 1k5; R_0402_1005Metric
R22: 1k8; R_0402_1005Metric
R23: 1k; R_0402_1005Metric
R24, R25, R26, R27, R28, R31: 4k7; R_0402_1005Metric
R29: 10k; R_0402_1005Metric
R30: 220R; R_0402_1005Metric
U4: ST60A3H1; ST_VFBGA-23_AiP_2.95x4.07mm_P0.4mm
U5: PTN3222GM; NXP_XQFN-12_1.75x2.2mm_P0.4mm
U6: TXS0108E; TSSOP-20_4.4x6.5mm_P0.65mm

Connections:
+1V8: C24.1, C26.1, C27.1, R20.1, R24.2, R25.2, R26.2, R27.2, U5.11 (ADDR), U5.12 (VDD1V8), U6.2 (VCCA); also elsewhere on the board
+3V3: C25.1, C28.1, C29.1, R30.1, U5.10 (VDD3V3), U6.19 (VCCB); also elsewhere on the board
CFG_SCL: U6.14 (B6); also elsewhere on the board
CFG_SDA: U6.15 (B5); also elsewhere on the board
EUSB_N: U4.C5 (TX_IN), U4.L5 (RX_ON), U5.3 (eDN)
EUSB_P: U4.C4 (TX_IP), U4.L4 (RX_OP), U5.2 (eDP)
GND: C21.2, C22.2, C24.2, C25.2, C26.2, C27.2, C28.2, C29.2, Q1.2 (E), R22.2, R23.2, R28.2, R31.2, U4.A3 (GND), U4.A4 (GND), U4.A5 (GND), U4.C6 (GND), U4.L6 (GND), U4.N3 (GND), U4.N4 (GND), U4.N5 (GND), U5.1 (DGND), U5.4 (AGND), U6.11 (GND); also elsewhere on the board
LINK_A: D2.2 (A), R30.2
LINK_B: Q1.1 (B), R29.2
LINK_K: D2.1 (K), Q1.3 (C)
LS_OE: R28.1, U6.10 (OE); also elsewhere on the board
RF_EN_GP: R21.1; also elsewhere on the board
RPT_DM: U5.8 (DN); also elsewhere on the board
RPT_DP: U5.9 (DP); also elsewhere on the board
ST_G0: U4.B2 (GPIO[0]), U6.9 (A8)
ST_G1: U4.D1 (GPIO[1]), U6.8 (A7)
ST_G2: R26.1, U4.K1 (GPIO[2]), U6.3 (A2)
ST_G3: R27.1, U4.M2 (GPIO[3]), U6.1 (A1)
ST_INT: U6.16 (B4); also elsewhere on the board
ST_LINK: U6.17 (B3); also elsewhere on the board
ST_LINK_STATUS: R23.1, R29.1, U4.J1 (LINK_STATUS), U5.5 (RST_N), U6.4 (A3)
ST_MODE_INT: R31.1, U4.G1 (MODE_INT), U6.5 (A4)
ST_RF_EN: R21.2, R22.1, U4.H1 (RF_EN)
ST_SCL: R24.1, U4.E1 (CFG_SCL), U5.7 (SCL), U6.7 (A6)
ST_SDA: R25.1, U4.F1 (CFG_SDA), U5.6 (SDA), U6.6 (A5)
ST_VDD: C21.1, C22.1, R20.2, U4.C3 (VDD_1V8), U4.L3 (VDD_IO)
TUN_G0: U6.12 (B8); also elsewhere on the board
TUN_G1: U6.13 (B7); also elsewhere on the board
TUN_G2: U6.18 (B2); also elsewhere on the board
TUN_G3: U6.20 (B1); also elsewhere on the board

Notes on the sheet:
eUSB2 repeater
ST60A3H1
1.8 V - 3.3 V translator
Link LED
After ST's X-NUCLEO-60K1A1 (B2379A): the ST60A3H1 on +1V8 through a 0 R link, the PTN3222 on its eUSB2 pair and held in reset by LINK_STATUS, an eight-channel auto-direction translator to 3.3 V (TXS0108E here, ST2378E there), RF_EN by divider, the link LED off an NPN. The translator is off (LS_OE l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

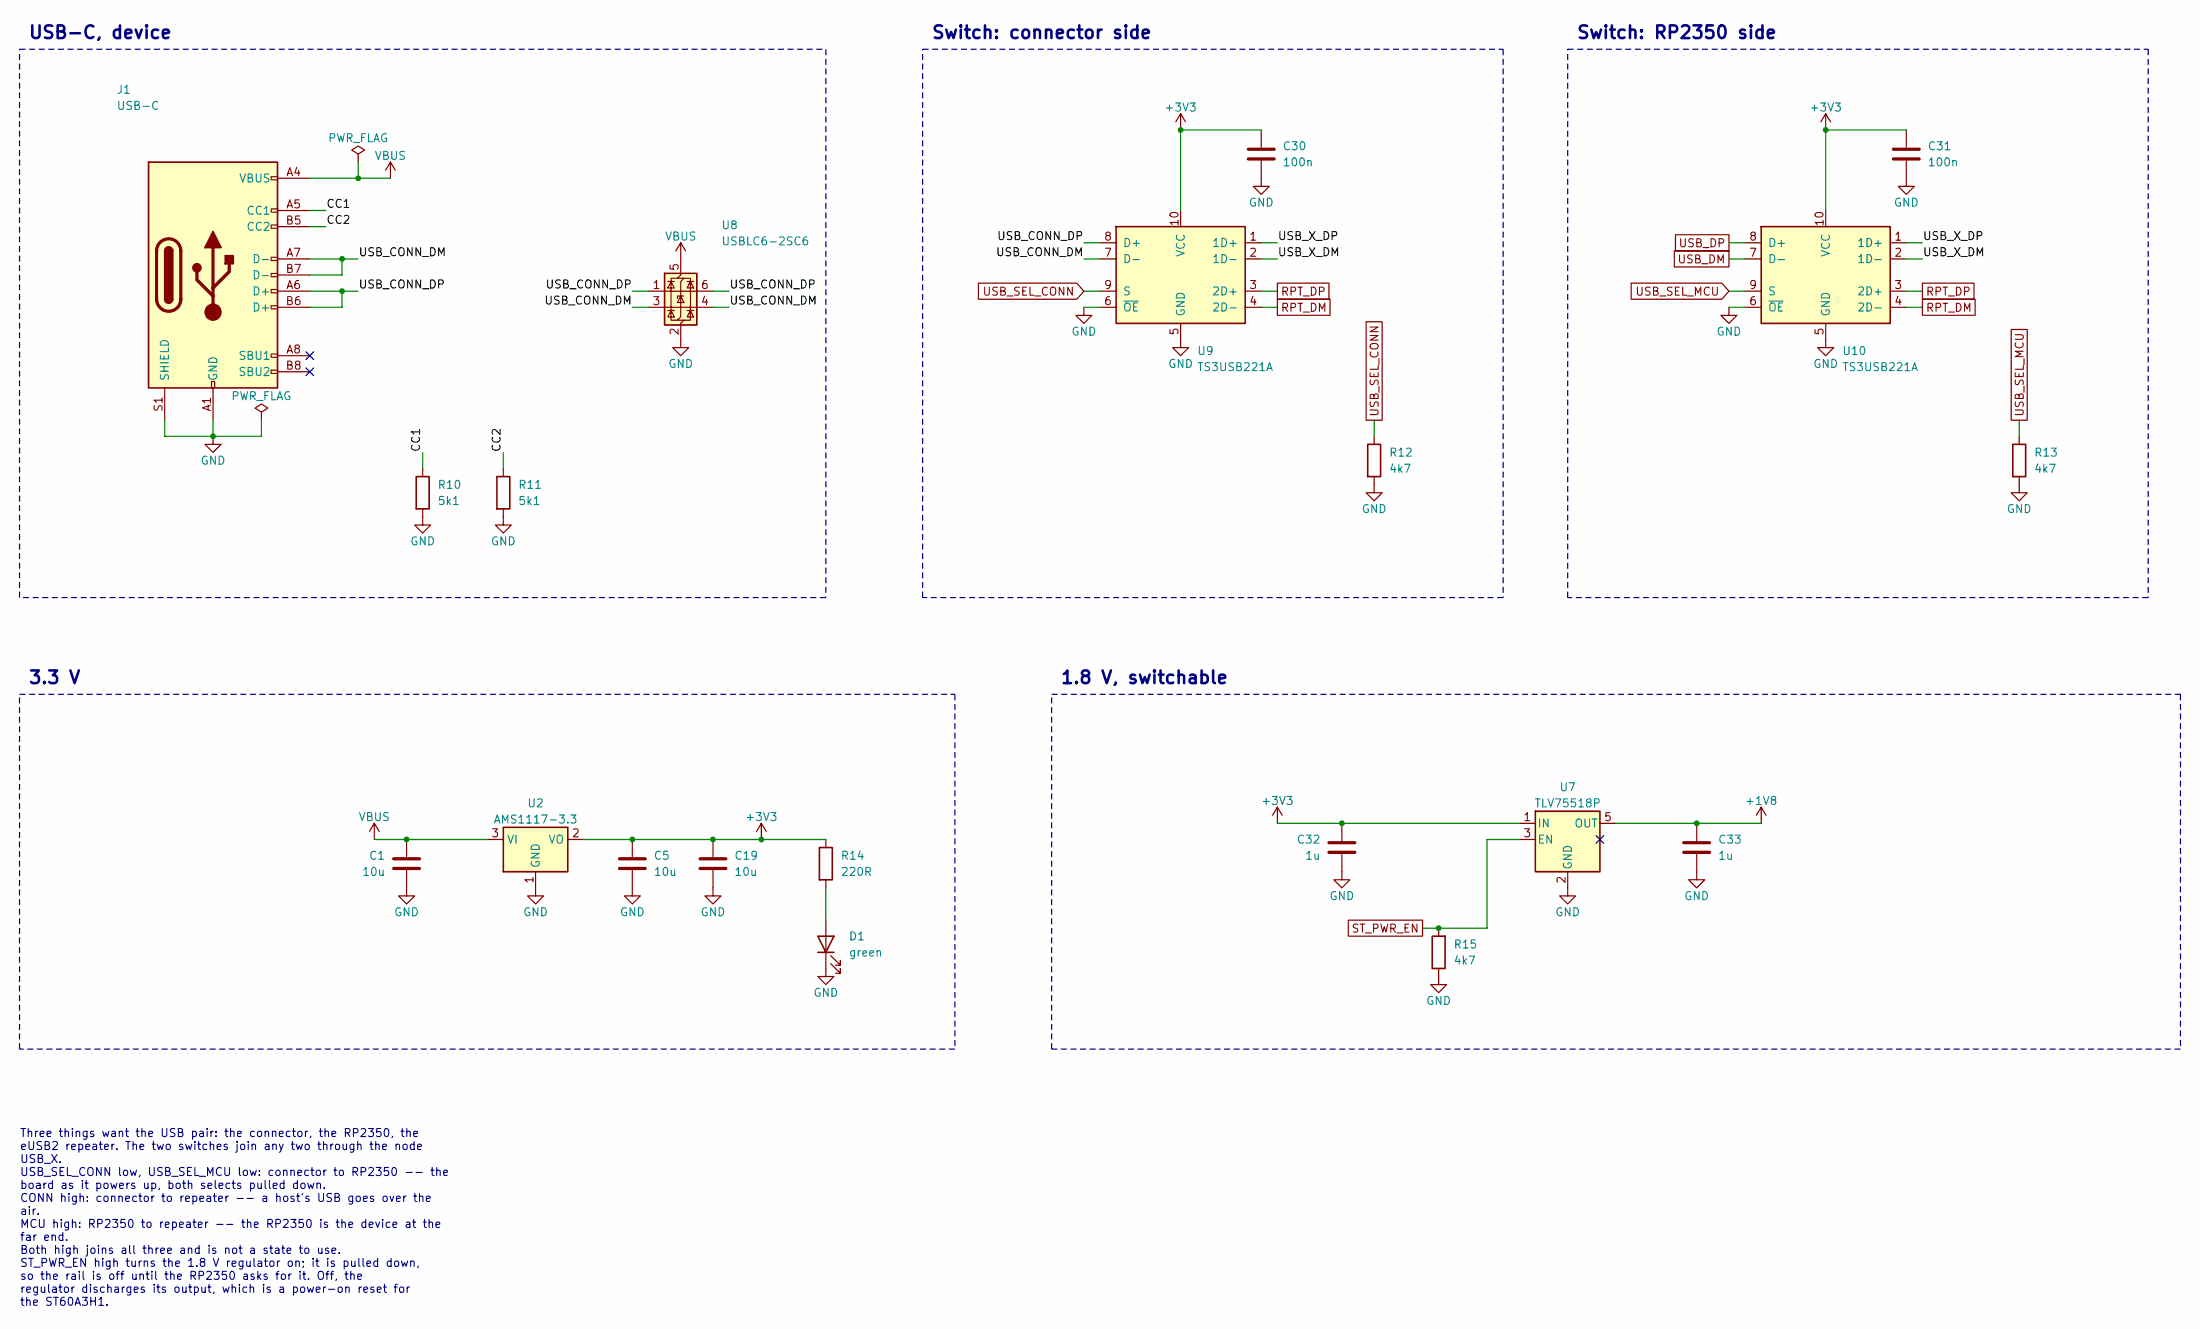
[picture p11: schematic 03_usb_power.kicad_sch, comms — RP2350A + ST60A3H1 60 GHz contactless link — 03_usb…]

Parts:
C1, C5, C19: 10u; C_0805_2012Metric
C30, C31: 100n; C_0402_1005Metric
C32, C33: 1u; C_0402_1005Metric
D1: green; LED_0603_1608Metric
J1: USB-C; USB_C_Receptacle_HRO_TYPE-C-31-M-12
R10, R11: 5k1; R_0402_1005Metric
R12, R13, R15: 4k7; R_0402_1005Metric
R14: 220R; R_0402_1005Metric
U2: AMS1117-3.3; SOT-223-3_TabPin2
U7: TLV75518P; SOT-23-5
U8: USBLC6-2SC6; SOT-23-6
U9, U10: TS3USB221A; Texas_UQFN-10_1.5x2mm_P0.5mm

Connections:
+1V8: C33.1, U7.5 (OUT); also elsewhere on the board
+3V3: C5.1, C19.1, C30.1, C31.1, C32.1, R14.1, U2.2 (VO), U7.1 (IN), U9.10 (VCC), U10.10 (VCC); also elsewhere on the board
CC1: J1.A5 (CC1), R10.1
CC2: J1.B5 (CC2), R11.1
GND: C1.2, C5.2, C19.2, C30.2, C31.2, C32.2, C33.2, D1.1 (K), J1.A1 (GND), J1.A12 (GND), J1.B1 (GND), J1.B12 (GND), J1.S1 (SHIELD), R10.2, R11.2, R12.2, R13.2, R15.1, U2.1 (GND), U7.2 (GND), U8.2 (GND), U9.5 (GND), U9.6 (~OE), U10.5 (GND), U10.6 (~OE); also elsewhere on the board
PWR_A: D1.2 (A), R14.2
RPT_DM: U9.4 (2D-), U10.4 (2D-); also elsewhere on the board
RPT_DP: U9.3 (2D+), U10.3 (2D+); also elsewhere on the board
ST_PWR_EN: R15.2, U7.3 (EN); also elsewhere on the board
USB_CONN_DM: J1.A7 (D-), J1.B7 (D-), U8.3 (I/O2), U8.4 (I/O2), U9.7 (D-)
USB_CONN_DP: J1.A6 (D+), J1.B6 (D+), U8.1 (I/O1), U8.6 (I/O1), U9.8 (D+)
USB_DM: U10.7 (D-); also elsewhere on the board
USB_DP: U10.8 (D+); also elsewhere on the board
USB_SEL_CONN: R12.1, U9.9 (S); also elsewhere on the board
USB_SEL_MCU: R13.1, U10.9 (S); also elsewhere on the board
USB_X_DM: U9.2 (1D-), U10.2 (1D-)
USB_X_DP: U9.1 (1D+), U10.1 (1D+)
VBUS: C1.1, J1.A4 (VBUS), J1.A9 (VBUS), J1.B4 (VBUS), J1.B9 (VBUS), U2.3 (VI), U8.5 (VBUS); also elsewhere on the board

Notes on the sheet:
USB-C, device
Switch: connector side
Switch: RP2350 side
3.3 V
1.8 V, switchable
Three things want the USB pair: the connector, the RP2350, the eUSB2 repeater. The two switches join any two through the node USB_X. USB_SEL_CONN low, USB_SEL_MCU low: connector to RP2350 -- the board as it powers up, both selects pulled down. CONN high: connector to repeater -- a host's USB goes o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

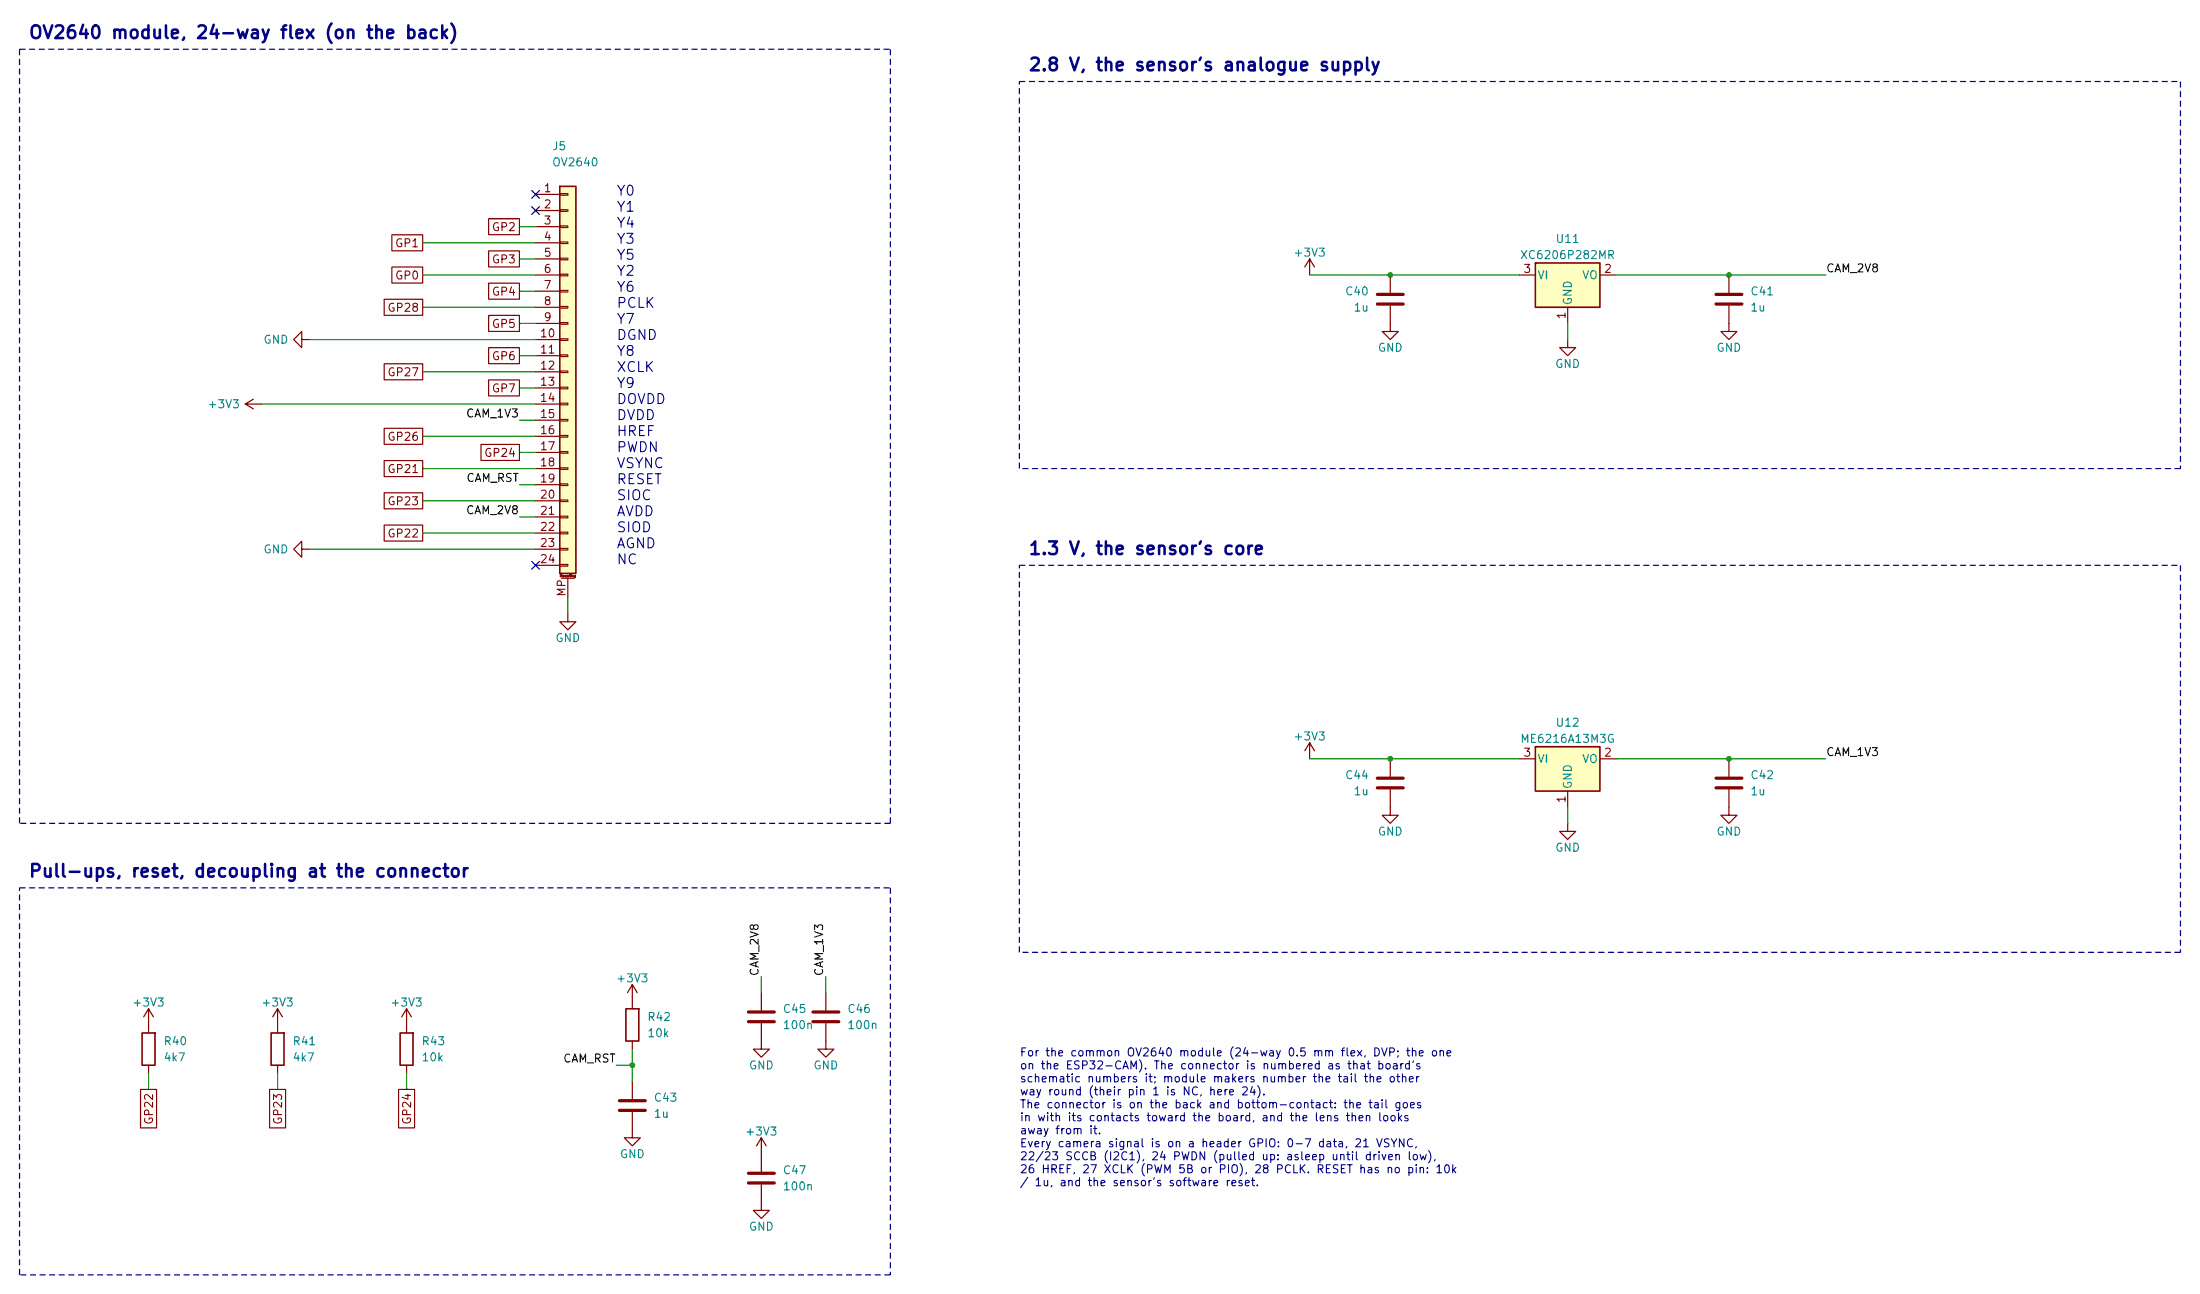
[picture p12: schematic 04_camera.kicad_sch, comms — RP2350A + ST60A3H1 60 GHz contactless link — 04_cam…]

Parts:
C40, C41, C42, C43, C44: 1u; C_0402_1005Metric
C45, C46, C47: 100n; C_0402_1005Metric
J5: OV2640; Hirose_FH12-24S-0.5SH_1x24-1MP_P0.50mm_Horizontal
R40, R41: 4k7; R_0402_1005Metric
R42, R43: 10k; R_0402_1005Metric
U11: XC6206P282MR; SOT-23
U12: ME6216A13M3G; SOT-23

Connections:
+3V3: C40.1, C44.1, C47.1, J5.14, R40.2, R41.2, R42.2, R43.2, U11.3 (VI), U12.3 (VI); also elsewhere on the board
CAM_1V3: C42.1, C46.1, J5.15, U12.2 (VO)
CAM_2V8: C41.1, C45.1, J5.21, U11.2 (VO)
CAM_RST: C43.1, J5.19, R42.1
GND: C40.2, C41.2, C42.2, C43.2, C44.2, C45.2, C46.2, C47.2, J5.10, J5.23, J5.MP (MountPin), U11.1 (GND), U12.1 (GND); also elsewhere on the board
GP0: J5.6; also elsewhere on the board
GP1: J5.4; also elsewhere on the board
GP2: J5.3; also elsewhere on the board
GP3: J5.5; also elsewhere on the board
GP4: J5.7; also elsewhere on the board
GP5: J5.9; also elsewhere on the board
GP6: J5.11; also elsewhere on the board
GP7: J5.13; also elsewhere on the board
GP21: J5.18; also elsewhere on the board
GP22: J5.22, R40.1; also elsewhere on the board
GP23: J5.20, R41.1; also elsewhere on the board
GP24: J5.17, R43.1; also elsewhere on the board
GP26: J5.16; also elsewhere on the board
GP27: J5.12; also elsewhere on the board
GP28: J5.8; also elsewhere on the board

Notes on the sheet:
OV2640 module, 24-way flex (on the back)
Pull-ups, reset, decoupling at the connector
2.8 V, the sensor's analogue supply
1.3 V, the sensor's core
Y0 Y1 Y4 Y3 Y5 Y2 Y6 PCLK Y7 DGND Y8 XCLK Y9 DOVDD DVDD HREF PWDN VSYNC RESET SIOC AVDD SIOD AGND NC
For the common OV2640 module (24-way 0.5 mm flex, DVP; the one on the ESP32-CAM). The connector is numbered as that board's schematic numbers it; module makers number the tail the other way round (their pin 1 is NC, here 24). The connector is on the back and bottom-contact: the tail goes in with it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

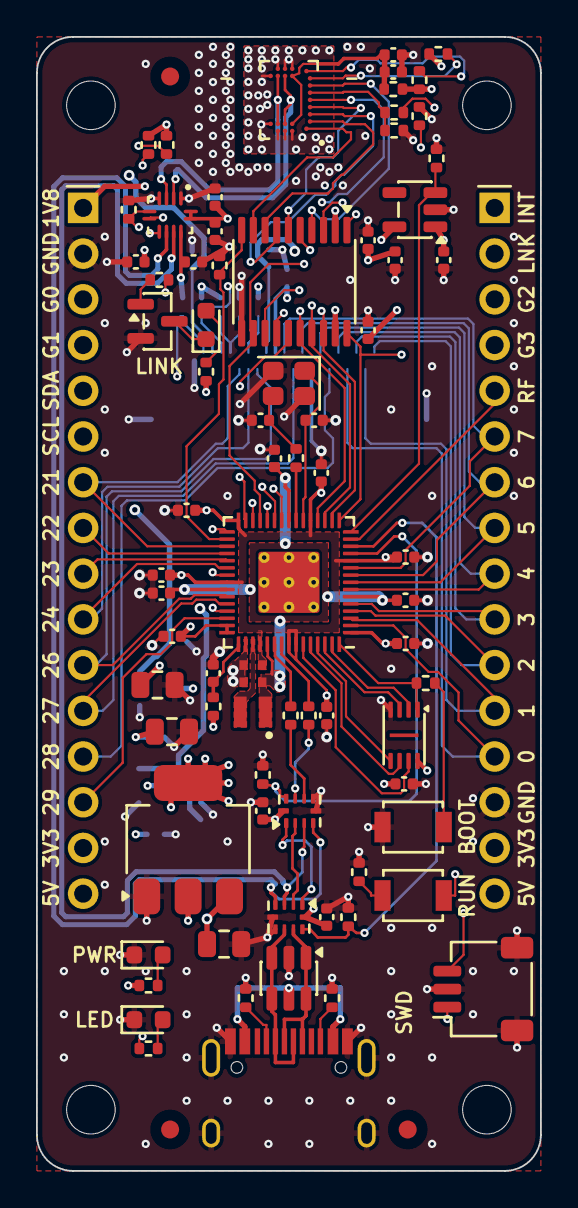
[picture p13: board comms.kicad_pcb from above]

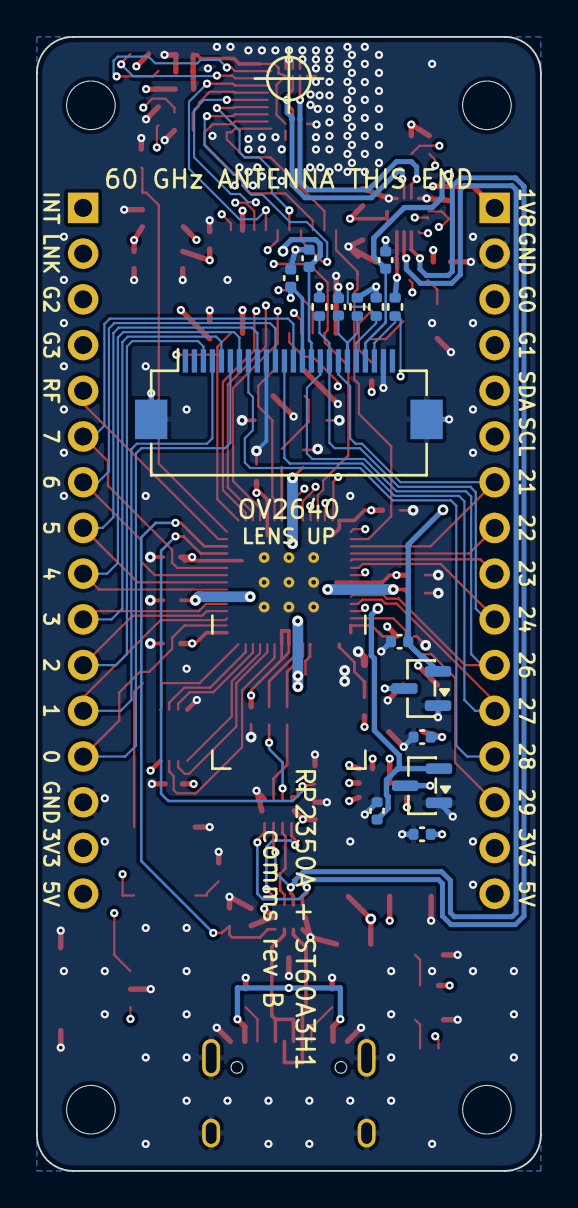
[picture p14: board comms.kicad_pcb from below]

Board: 6 copper layers, 28.0 x 63.0 mm, 100 parts (15 on the bottom side), 83 nets.

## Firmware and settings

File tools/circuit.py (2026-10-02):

#!/usr/bin/env python3
"""circuit.py -- the comms board's netlist, as data.

The circuit is DATA here, not drawing: every component is a reference, a
symbol, a value, a footprint and a pin-to-net map. The schematic
(tools/schlayout.py) is drawn from it and the board (tools/gen_board.py) is
built from it, so the two cannot disagree; KiCad's own netlist export is
compared with it net by net (tools/check.py).

    python3 tools/circuit.py          # the netlist report and the checks

What the board is: an RP2350A beside an ST60A3H1, ST's 60 GHz contactless
transceiver with the antenna in the package. Two of these boards face each
other a few centimetres apart and tunnel UART, GPIO, I2C or eUSB2 between
them. The same board is either end: which is Local and which Remote is the
ST60's configuration, written by the RP2350 over I2C.

Where each block comes from:

  - the RP2350A, its core regulator, crystal, flash and decoupling:
    Raspberry Pi's RP2350A minimal design (RP-006440), part for part
  - the ST60A3H1, its supply, the eUSB2 repeater and the 1.8 V translator:
    ST's X-NUCLEO-60K1A1 (boards B2379A, schematic rev 1), with a TXS0108E
    where ST has its own ST2378E
  - sourcing and the passives' values: servodrive's hardware/parts/lcsc.csv
"""
import os
import uuid
from pathlib import Path

import sexp

ROOT = Path(__file__).resolve().parent.parent
KSYM = Path("/usr/share/kicad/symbols")
PROJ_SYM = ROOT / "hardware/parts/comms.kicad_sym"
PROJECT = "comms"

# Deterministic UUIDs, so re-running produces byte-identical files.
NS = uuid.UUID("5c0e60a3-0000-4000-8000-000000000000")
def _uid(*parts):
    return str(uuid.uuid5(NS, "/".join(str(p) for p in parts)))

# ------------------------------------------------------------- libraries ----
_LIBS, _SYMS, _PINS = {}, {}, {}

def _lib(nick):
    if nick not in _LIBS:
        path = PROJ_SYM if nick == PROJECT else KSYM / f"{nick}.kicad_sym"
        _LIBS[nick] = sexp.parse(path.read_text())
    return _LIBS[nick]

def symbol(lib_id):
    """The symbol definition, with any `extends` resolved into it.

    A schematic carries its own copy of every symbol it uses, and a derived
    symbol whose base is not also present will not load. Flattening is simpler
    than shipping both and hoping KiCad resolves the bare base name.
    """
    if lib_id in _SYMS:
        return _SYMS[lib_id]
    nick, name = lib_id.split(":", 1)
    root = _lib(nick)
    src = next((s for s in sexp.findall(root, "symbol")
                if sexp.unq(s[1]) == name), None)
    if src is None:
        raise KeyError(f"no symbol {lib_id}")
    ext = sexp.find(src, "extends")
    if ext:
        base = next(s for s in sexp.findall(root, "symbol")
                    if sexp.unq(s[1]) == sexp.unq(ext[1]))
        out = ["symbol", sexp.q(lib_id)]
        for c in base[2:]:                      # graphics, pins, base flags
            if isinstance(c, list) and c[0] in ("property", "extends"):
                continue
            out.append(_rename_units(c, sexp.unq(base[1]), name))
        for c in src[2:]:                       # the derived part's own fields
            if isinstance(c, list) and c[0] == "property":
                out.append(c)
        for c in base[2:]:                      # anything the derived one lacks
            if isinstance(c, list) and c[0] == "property":
                nm = sexp.unq(c[1])
                if not any(sexp.unq(d[1]) == nm
                           for d in sexp.findall(out, "property")):
                    out.append(c)
    else:
        out = ["symbol", sexp.q(lib_id)] + [
            _rename_units(c, name, name) for c in src[2:]]
    _SYMS[lib_id] = out
    return out

def _rename_units(node, old, new):
    """Sub-symbols are named "<parent>_<unit>_<style>", and the parent there is
    the UNQUALIFIED name even when the symbol itself is stored as "Lib:Name"."""
    if isinstance(node, list) and node and node[0] == "symbol":
        nm = sexp.unq(node[1])
        if nm.startswith(old + "_"):
            node = ["symbol", sexp.q(new + nm[len(old):])] + node[2:]
    return node

def pins(lib_id):
    """{number: (x, y, rot, name, etype)} in library coordinates."""
    if lib_id in _PINS:
        return _PINS[lib_id]
    out = {}
    for p in sexp.walk(symbol(lib_id), "pin"):
        at = sexp.find(p, "at")
        nb, nm = sexp.find(p, "number"), sexp.find(p, "name")
        if not (at and nb):
            continue
        out[sexp.unq(nb[1])] = (float(at[1]), float(at[2]), float(at[3]),
                                sexp.unq(nm[1]) if nm else "", p[1])
    _PINS[lib_id] = out
    return out

# ---------------------------------------------------------------- netlist ---
class Comp:
    __slots__ = ("ref", "lib_id", "value", "fp", "nets", "sheet", "group",
                 "dnp", "note")

    def __init__(self, ref, lib_id, value, fp, nets, sheet, group, dnp=False,
                 note=""):
        self.ref, self.lib_id, self.value, self.fp = ref, lib_id, value, fp
        self.nets, self.sheet, self.group, self.dnp = nets, sheet, group, dnp
        self.note = note

R = "Device:R"
C = "Device:C"
L = "Device:L"
LED = "Device:LED"

FP_R = {"0402": "Resistor_SMD:R_0402_1005Metric"}
FP_C = {"0402": "Capacitor_SMD:C_0402_1005Metric",
        "0402s": "comms:C_0402_1005Metric_small_pads",   # the reference's, at the core regulator
        "0805": "Capacitor_SMD:C_0805_2012Metric"}
FP_LED = "LED_SMD:LED_0603_1608Metric"
FP_SW = "Button_Switch_SMD:SW_SPST_B3U-1000P"
FP_HDR = "Connector_PinHeader_2.54mm:PinHeader_1x16_P2.54mm_Vertical"

# Supplies. VBUS is the USB-C connector's 5 V; ST_VDD is +1V8 after the 0 R
# link that lets the ST60's current be measured on its own.
PWR = {"GND", "VBUS", "+3V3", "+1V8", "+1V1"}

# The RP2350's GPIO. The chip sits turned half round, so that its USB and
# QSPI side faces the USB-C connector at the bottom edge and the side with
# GPIO12-18 faces the translator. Every signal leaves the chip on the side
# it is wanted: what goes to the ST60 from the top, what goes to the bottom
# of the board from the bottom of a side, the rest straight out to a header.
#
#   0..7     the right-hand header
#   8..11    USB path selects, RF_EN, the 1.8 V regulator's enable: the four
#            pins at the open top-right corner, where each has room for the
#            via it needs (lower down the side the decoupling capacitors
#            leave four pins a gap four tracks wide, and no more)
#   12..19   the ST60, through the translator
#   20       the translator's enable
#   21..24, 26..29 (the ADC pins)   the left-hand header;  25 the LED
#
# An OV2640 camera, when one is plugged in, takes 0..7, 21..24 and 26..28
# off the headers (see CAM, below).
#
# Every tunnelling mode the ST60 offers lands on a hardware peripheral, and
# the configuration bus has one to itself:
#
#   16/17   UART0 TX/RX      GPIO[0] is the tunnel's TXD, GPIO[1] its RXD
#   12/13   I2C0 SDA/SCL     GPIO[3]/GPIO[2], the tunnelled SDA/SCL
#   18/19   I2C1 SDA/SCL     the configuration bus
#
# (0/1 on the header are UART0 TX/RX as well, the usual place; 4/5 are UART1.)
GP = {
    8: "USB_SEL_MCU",    # high: the RP2350's own USB goes to the repeater
    9: "USB_SEL_CONN",   # high: the USB-C connector goes to the eUSB2 repeater
    10: "RF_EN_GP",      # RF_EN, through the divider to 1.8 V
    11: "ST_PWR_EN",     # high: the 1.8 V regulator on. Low, or not driven: off (a cold reset of the ST60)
    12: "TUN_G3",        # I2C0 SDA <-> ST60 GPIO[3], the tunnelled SDA
    13: "TUN_G2",        # I2C0 SCL <-> ST60 GPIO[2], the tunnelled SCL
    14: "ST_LINK",       # LINK_STATUS
    15: "ST_INT",        # MODE_INT
    16: "TUN_G0",        # UART0 TX -> ST60 GPIO[0], the tunnelled TXD
    17: "TUN_G1",        # UART0 RX <- ST60 GPIO[1], the tunnelled RXD
    18: "CFG_SDA",       # I2C1: the ST60's configuration port (0x60) and the
    19: "CFG_SCL",       #   PTN3222's (0x43)
    20: "LS_OE",         # the translator's output enable
    25: "LED",
}
HEADER_GPIO = list(range(0, 8)) + [21, 22, 23, 24, 26, 27, 28, 29]
for _g in HEADER_GPIO:
    GP[_g] = f"GP{_g}"

SHEETS = [
    ("01_mcu", "RP2350A, core regulator, crystal, QSPI flash, SWD, buttons, headers"),
    ("02_link", "ST60A3H1, 1.8 V translator, eUSB2 repeater, link LED"),
    ("03_usb_power", "USB-C, USB path switches, 3.3 V and 1.8 V regulators"),
    ("04_camera", "OV2640 camera module connector, its 2.8 V and 1.3 V supplies"),
]
REV = "B"


def mcu():
    """01_mcu: the RP2350A and everything it cannot run without, as
    Raspberry Pi's minimal design has it."""
    sh, out = "01_mcu", []
    def add(ref, lib_id, value, fp, nets, group, note="", dnp=False):
        out.append(Comp(ref, lib_id, value, fp, nets, sh, group, dnp, note))

    cpu = {}
    for pin, name in (("1", "+3V3"), ("11", "+3V3"), ("20", "+3V3"),
                      ("30", "+3V3"), ("38", "+3V3"), ("45", "+3V3"),
                      ("6", "+1V1"), ("23", "+1V1"), ("39", "+1V1"),
                      ("61", "GND"), ("21", "XIN"), ("22", "XOUT"),
                      ("24", "SWCLK"), ("25", "SWDIO"), ("26", "RUN"),
                      # 44 ADC_AVDD and 45 IOVDD on +3V3, as the reference;
                      # 46 VREG_AVDD through 33 R; 47 VREG_PGND; 48 VREG_LX;
                      # 49 VREG_VIN; 50 VREG_FB; 53 USB_OTP_VDD; 54 QSPI_IOVDD
                      ("44", "+3V3"), ("46", "VREG_AVDD"), ("47", "GND"),
                      ("48", "VREG_LX"), ("49", "+3V3"), ("50", "+1V1"),
                      ("51", "USB_DM_C"), ("52", "USB_DP_C"),
                      ("53", "+3V3"), ("54", "+3V3"),
                      ("55", "QSPI_SD3"), ("56", "QSPI_SCLK"),
                      ("57", "QSPI_SD0"), ("58", "QSPI_SD2"),
                      ("59", "QSPI_SD1"), ("60", "QSPI_SS")):
        cpu[pin] = name
    # GPIO0..29 land on pins 2..5, 7..10, 12..19, 27..29, 31..37, 40..43
    order = [2, 3, 4, 5, 7, 8, 9, 10, 12, 13, 14, 15, 16, 17, 18, 19,
             27, 28, 29, 31, 32, 33, 34, 35, 36, 37, 40, 41, 42, 43]
    for g, pin in zip(range(30), order):
        cpu[str(pin)] = GP[g]
    add("U1", "comms:RP2350_60QFN", "RP2350A",
        "comms:RP2350-QFN-60-1EP_7x7_P0.4mm_EP3.4x3.4mm_ThermalVias",
        cpu, "CPU", "QFN-60; turned so USB and QSPI face the connector")

    # The core regulator, the reference's references in brackets: 3.3 uH
    # from VREG_LX (L1), 4.7 u on its output beside it (C7) and on VREG_VIN
    # (C6), VREG_AVDD through 33 R (R5) with its own 4.7 u (C9), 4.7 u more
    # on DVDD at pin 23 (C10). The inductor's pad 1 is the output.
    add("L1", L, "3u3", "comms:L_pol_2016",
        {"1": "+1V1", "2": "VREG_LX"}, "core rail",
        "core buck: VREG_LX -> DVDD. 3.3 uH 2016, polarised, as the reference")
    add("C6", C, "4u7", FP_C["0402s"], {"1": "+3V3", "2": "GND"}, "core rail",
        "VREG_VIN, at pin 49")
    add("C7", C, "4u7", FP_C["0402s"], {"1": "+1V1", "2": "GND"}, "core rail",
        "DVDD, at the inductor")
    add("C9", C, "4u7", FP_C["0402"], {"1": "VREG_AVDD", "2": "GND"}, "core rail",
        "VREG_AVDD")
    add("R5", R, "33R", FP_R["0402"], {"1": "+3V3", "2": "VREG_AVDD"}, "core rail",
        "+3V3 -> VREG_AVDD")
    add("C10", C, "4u7", FP_C["0402"], {"1": "+1V1", "2": "GND"}, "core rail",
        "DVDD, at pin 23")
    # 100 n as the reference has them: two on DVDD (pins 6 and 39; pin 23
    # has the 4.7 u), seven on the 3V3 pins
    for ref, pin in (("C8", 6), ("C11", 39)):
        add(ref, C, "100n", FP_C["0402"], {"1": "+1V1", "2": "GND"}, "decoupling",
            f"DVDD, pin {pin}")
    for ref, pin in (("C12", "53/54"), ("C13", "1"), ("C14", "38"), ("C15", "11"),
                     ("C16", "30"), ("C17", "44/45"), ("C18", "20")):
        add(ref, C, "100n", FP_C["0402"], {"1": "+3V3", "2": "GND"}, "decoupling",
            f"IOVDD, pin {pin}")
    add("R7", R, "27R", FP_R["0402"], {"1": "USB_DP", "2": "USB_DP_C"}, "USB",
        "USB_DP series")
    add("R8", R, "27R", FP_R["0402"], {"1": "USB_DM", "2": "USB_DM_C"}, "USB",
        "USB_DM series")

    # Crystal: servodrive's part (CL 20 pF, 2520) and its 27 p, where the
    # reference has an ABM8-272 and 15 p; the 1 k on XOUT is the reference's.
    add("Y1", "Device:Crystal_GND24", "12MHz",
        "Crystal:Crystal_SMD_2520-4Pin_2.5x2.0mm",
        {"1": "XIN", "2": "GND", "3": "XTAL2", "4": "GND"}, "clock",
        "12 MHz 2520, CL 20 pF")
    add("R2", R, "1k", FP_R["0402"], {"1": "XOUT", "2": "XTAL2"}, "clock",
        "crystal series, on XOUT")
    add("C3", C, "27p", FP_C["0402"], {"1": "XIN", "2": "GND"}, "clock", "crystal load")
    add("C4", C, "27p", FP_C["0402"], {"1": "XTAL2", "2": "GND"}, "clock", "crystal load")

    add("U3", "comms:W25Q16JV", "W25Q16JVUXIQ",
        "Package_SON:Winbond_USON-8-1EP_3x2mm_P0.5mm_EP0.2x1.6mm",
        {"1": "QSPI_SS", "2": "QSPI_SD1", "3": "QSPI_SD2", "4": "GND",
         "5": "QSPI_SD0", "6": "QSPI_SCLK", "7": "QSPI_SD3", "8": "+3V3"},
        "QSPI flash", "16 Mbit QSPI flash")
    add("C2", C, "100n", FP_C["0402"], {"1": "+3V3", "2": "GND"}, "QSPI flash",
        "flash decoupling")
    add("R6", R, "1k", FP_R["0402"], {"1": "QSPI_SS", "2": "BOOTSEL"},
        "QSPI flash", "BOOTSEL series")
    add("SW1", "Switch:SW_Push", "BOOTSEL", FP_SW,
        {"1": "GND", "2": "BOOTSEL"}, "buttons", "hold while resetting: USB boot")
    add("SW2", "Switch:SW_Push", "RUN", FP_SW,
        {"1": "RUN_SW", "2": "RUN"}, "buttons", "reset")
    add("R4", R, "1k", FP_R["0402"], {"1": "RUN_SW", "2": "GND"}, "buttons",
        "RUN button series")

    add("J4", "Connector_Generic_MountingPin:Conn_01x03_MountingPin", "SWD",
        "Connector_JST:JST_SH_SM03B-SRSS-TB_1x03-1MP_P1.00mm_Horizontal",
        {"1": "SWCLK", "2": "GND", "3": "SWDIO", "MP": "GND"}, "debug",
        "Raspberry Pi debug connector: SWCLK, GND, SWDIO")

    add("D3", LED, "blue", FP_LED, {"1": "GND", "2": "LED_A"}, "LED", "user LED, GPIO25")
    add("R9", R, "220R", FP_R["0402"], {"1": "LED", "2": "LED_A"}, "LED", "LED series (Vf 3.1 V)")

    # The headers, 0.9 inch apart. Each runs in the order the chip's pins
    # come off that side, so nothing crosses on the way out. Besides GPIO
    # they carry the 3.3 V side of everything the ST60 needs from a host --
    # the four tunnelled lines, the configuration bus, RF_EN, the interrupt
    # and the link status -- so a host that is not the RP2350 can run the
    # link: the RP2350 enables the translator and lets go of those pins.
    j2 = ["+1V8", "GND", "TUN_G0", "TUN_G1", "CFG_SDA", "CFG_SCL", "GP21", "GP22",
          "GP23", "GP24", "GP26", "GP27", "GP28", "GP29", "+3V3", "VBUS"]
    j3 = ["ST_INT", "ST_LINK", "TUN_G2", "TUN_G3", "RF_EN_GP", "GP7", "GP6", "GP5",
          "GP4", "GP3", "GP2", "GP1", "GP0", "GND", "+3V3", "VBUS"]
    add("J2", "Connector_Generic:Conn_01x16", "LEFT", FP_HDR,
        {str(i + 1): n for i, n in enumerate(j2)}, "headers",
        "tunnelled UART, configuration bus, GPIO21-24 and the ADC pins, rails")
    add("J3", "Connector_Generic:Conn_01x16", "RIGHT", FP_HDR,
        {str(i + 1): n for i, n in enumerate(j3)}, "headers",
        "link status and interrupt, tunnelled I2C, RF_EN, GPIO0-7, rails")
    return out


def link():
    """02_link: the ST60A3H1 and what stands between it and 3.3 V logic --
    ST's X-NUCLEO-60K1A1, sheet 1, with the Nucleo's place taken by the
    RP2350."""
    sh, out = "02_link", []
    def add(ref, lib_id, value, fp, nets, group, note="", dnp=False):
        out.append(Comp(ref, lib_id, value, fp, nets, sh, group, dnp, note))

    st = {"A3": "GND", "A4": "GND", "A5": "GND", "C6": "GND", "L6": "GND",
          "N3": "GND", "N4": "GND", "N5": "GND",
          "C3": "ST_VDD", "L3": "ST_VDD",          # VDD_1V8 and VDD_IO, tied on the board (DS 2.7.1.1)
          "B2": "ST_G0", "D1": "ST_G1", "K1": "ST_G2", "M2": "ST_G3",
          "E1": "ST_SCL", "F1": "ST_SDA",
          "G1": "ST_MODE_INT", "H1": "ST_RF_EN", "J1": "ST_LINK_STATUS",
          # eUSB2: TX_IP with RX_OP and TX_IN with RX_ON, tied on the board
          # (DS fig. 4, note 1)
          "C4": "EUSB_P", "L4": "EUSB_P", "C5": "EUSB_N", "L5": "EUSB_N"}
    add("U4", "comms:ST60A3H1", "ST60A3H1",
        "comms:ST_VFBGA-23_AiP_2.95x4.07mm_P0.4mm", st, "ST60",
        "60 GHz transceiver, antenna in package; the patch is 1.18 mm toward row N from the centre")
    add("R20", R, "0R", FP_R["0402"], {"1": "+1V8", "2": "ST_VDD"}, "ST60",
        "the ST60's supply link: lift it to measure the current")
    add("C21", C, "100n", FP_C["0402"], {"1": "ST_VDD", "2": "GND"}, "ST60", "VDD_1V8, ball C3")
    add("C22", C, "100n", FP_C["0402"], {"1": "ST_VDD", "2": "GND"}, "ST60", "VDD_IO, ball L3")
    # No bulk here: the ST60 wants its supply to rise and fall in 50 us to
    # 1 ms (DS table 8), and the regulator's 120 R discharge has to empty
    # everything on the rail in that time. 1 u at the regulator, 470 n at the
    # repeater and three 100 n make 1.8 uF, about 0.5 ms from 90 % to 10 %.

    # RF_EN: 3.3 V to 1.8 V by divider, as ST does (1k5/1k8). The 1k8 also
    # holds RF_EN low against the ST60's internal pull-up until the RP2350
    # drives it, so the radio stays in RF_IDLE through a reset.
    add("R21", R, "1k5", FP_R["0402"], {"1": "RF_EN_GP", "2": "ST_RF_EN"}, "ST60", "RF_EN divider, top")
    add("R22", R, "1k8", FP_R["0402"], {"1": "ST_RF_EN", "2": "GND"}, "ST60", "RF_EN divider, bottom")
    # LINK_STATUS is an input with a weak pull-down until the ST60 has
    # booted, and the repeater's RST_N pulls up through 10 k: 1 k holds it low.
    add("R23", R, "1k", FP_R["0402"], {"1": "ST_LINK_STATUS", "2": "GND"}, "ST60",
        "LINK_STATUS pull-down, against the PTN3222's RST_N pull-up")
    # Pull-ups on the 1.8 V side of the configuration bus and of GPIO[2]/[3]
    # (the tunnelled SCL/SDA). The ST60 and the PTN3222 both ask for external
    # ones (DS14598 table 3, notes 1 and 4; PTN3222 table 5), and without
    # them GPIO[2]/[3] -- inputs with a 20-120 k pull-down after reset --
    # would sit mid-rail against the translator's 40 k pull-ups. 4k7 is as
    # low as the translator's pass gate lets the far side pull down cleanly;
    # anything added on the 3.3 V side (J2, J3) should be 8k2 or more.
    for ref, net in (("R24", "ST_SCL"), ("R25", "ST_SDA"), ("R26", "ST_G2"), ("R27", "ST_G3")):
        add(ref, R, "4k7", FP_R["0402"], {"1": net, "2": "+1V8"}, "ST60", f"{net} pull-up")
    # MODE_INT is a boot strap, read as 0 on the ST60's internal pull-down
    # alone. If the 1.8 V rail is cycled with the translator enabled, the
    # translator's 40 k pull-up would be pulling against it: 4k7 settles it.
    add("R31", R, "4k7", FP_R["0402"], {"1": "ST_MODE_INT", "2": "GND"}, "ST60",
        "MODE_INT strap: 0 at power-up, whatever the translator is doing")

    # The translator. A side at 1.8 V, B at 3.3 V; OE is referenced to VCCA
    # but takes 5.5 V, so the GPIO drives it directly. Pulled low: the ST60
    # boots with nothing but its own internal straps on its pins.
    # Channels in the order the ST60's balls come round to the A side:
    # nothing crosses between the island and the translator.
    ls = {"2": "+1V8", "19": "+3V3", "11": "GND", "10": "LS_OE",
          "9": "ST_G0", "12": "TUN_G0",                 # A8 / B8
          "8": "ST_G1", "13": "TUN_G1",                 # A7 / B7
          "7": "ST_SCL", "14": "CFG_SCL",               # A6 / B6
          "6": "ST_SDA", "15": "CFG_SDA",               # A5 / B5
          "5": "ST_MODE_INT", "16": "ST_INT",           # A4 / B4
          "4": "ST_LINK_STATUS", "17": "ST_LINK",       # A3 / B3
          "3": "ST_G2", "18": "TUN_G2",                 # A2 / B2
          "1": "ST_G3", "20": "TUN_G3"}                 # A1 / B1
    add("U6", "Logic_LevelTranslator:TXS0108EPW", "TXS0108E",
        "Package_SO:TSSOP-20_4.4x6.5mm_P0.65mm", ls, "translator",
        "1.8 V <-> 3.3 V, auto-direction, push-pull or open-drain")
    add("C24", C, "100n", FP_C["0402"], {"1": "+1V8", "2": "GND"}, "translator", "VCCA")
    add("C25", C, "100n", FP_C["0402"], {"1": "+3V3", "2": "GND"}, "translator", "VCCB")
    add("R28", R, "4k7", FP_R["0402"], {"1": "LS_OE", "2": "GND"}, "translator",
        "OE pull-down: translator off until the RP2350 says so")

    # The eUSB2 repeater, as ST has it: held in reset until the RF link is
    # up, on the configuration bus at 0x43 (ADDR on 1.8 V), though it needs
    # no configuration to work.
    add("U5", "comms:PTN3222", "PTN3222GM",
        "comms:NXP_XQFN-12_1.75x2.2mm_P0.4mm",
        {"1": "GND", "4": "GND", "2": "EUSB_P", "3": "EUSB_N",
         "5": "ST_LINK_STATUS", "6": "ST_SDA", "7": "ST_SCL",
         "8": "RPT_DM", "9": "RPT_DP", "10": "+3V3", "11": "+1V8", "12": "+1V8"},
        "repeater", "eUSB2 <-> USB 2.0 repeater, host or device side")
    add("C26", C, "470n", FP_C["0402"], {"1": "+1V8", "2": "GND"}, "repeater", "VDD1V8 (NXP's value)")
    add("C27", C, "100p", FP_C["0402"], {"1": "+1V8", "2": "GND"}, "repeater", "VDD1V8")
    add("C28", C, "1u", FP_C["0402"], {"1": "+3V3", "2": "GND"}, "repeater", "VDD3V3")
    add("C29", C, "100p", FP_C["0402"], {"1": "+3V3", "2": "GND"}, "repeater", "VDD3V3")

    # Link LED, off the 1.8 V LINK_STATUS through an NPN as ST does it.
    add("Q1", "Transistor_BJT:MMBT3904", "MMBT3904", "Package_TO_SOT_SMD:SOT-23",
        {"1": "LINK_B", "2": "GND", "3": "LINK_K"}, "link LED", "link LED driver")
    add("R29", R, "10k", FP_R["0402"], {"1": "ST_LINK_STATUS", "2": "LINK_B"},
        "link LED", "base resistor")
    add("D2", LED, "green", FP_LED, {"1": "LINK_K", "2": "LINK_A"}, "link LED",
        "lit while the RF link is up")
    add("R30", R, "220R", FP_R["0402"], {"1": "+3V3", "2": "LINK_A"}, "link LED",
        "LED series")
    return out
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

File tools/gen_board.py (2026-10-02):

#!/usr/bin/env python3
"""gen_board.py -- emit the comms KiCad project from the netlist and the placement.

    python3 tools/gen_board.py            # create anything missing
    python3 tools/gen_board.py --force    # overwrite, DESTROYS routing

What it writes, in hardware/comms/:

  comms.kicad_pro     design rules and net classes
  comms.kicad_pcb     the board: outline, parts, planes, and the copper that
                      is decided rather than routed (below)
  comms.kicad_sch + three sheets      (tools/schlayout.py draws them)
  fp-lib-table, sym-lib-table

The copper this file lays, all of it locked so the router leaves it alone:

  - round the RP2350, Raspberry Pi's: every track, via and pour that the
    RP2350A minimal design (RP-006440) has on the core regulator, the 1V1
    and 3V3 rings under the chip, the decoupling and the USB series
    resistors, read out of that board file and turned with the chip
  - under the ST60A3H1, ST's: the grounded island and the moat round it
    (antenna_ground), the eUSB2 pair tied TX to RX inside the ball field and
    taken out on the back, the supply balls into the ST_VDD plane
  - a via beside every surface-mount pad on a net that lives on a plane
    (GND, +3V3, +1V8, ST_VDD), so those nets never reach the router

What is left -- the signals -- tools/route.py hands to freerouting.

Refuses to overwrite an existing .kicad_pcb without --force: once the board
is routed, this script is no longer the source of truth for that file.
"""
import argparse
import json
import math
import os
import sys
from pathlib import Path

import pcbnew

sys.path.insert(0, str(Path(__file__).resolve().parent))
import circuit as CIR
import placement as PL
import copper as CU

ROOT = Path(__file__).resolve().parent.parent
HW = ROOT / "hardware" / "comms"
NAME = "comms"
PCB = HW / f"{NAME}.kicad_pcb"
PRO = HW / f"{NAME}.kicad_pro"
KFP = Path("/usr/share/kicad/footprints")
PROJ_FP = ROOT / "hardware/parts/comms.pretty"
RPI_REF = Path("/home/sequoia/pcb/RP-006440-DD-2-RP2350A Minimal Board Kicad archive"
               "/RP2350_60QFN_minimal.kicad_pcb")
uid = CIR._uid

# The board's origin (middle of the top edge) on the KiCad page.
OX, OY = 100.0, 40.0
mm = pcbnew.FromMM
def V(x, y):
    return pcbnew.VECTOR2I(mm(OX + x), mm(OY + y))

TITLE = "comms — RP2350A + ST60A3H1 60 GHz contactless link"
REV, DATE = "A", "2026-10-01"

# ------------------------------------------------------------ the stack ----
# JLCPCB's six-layer JLC06161H-7628: 0.21 mm of 7628 prepreg under each
# outer layer (as their four-layer stack has, so the antenna's ground and
# the USB pairs sit as they did on rev A), two 0.4 mm cores and 0.2 mm of
# prepreg between them.
#
#   F.Cu     parts, signals
#   In1.Cu   solid ground, directly under the parts and the antenna
#   In2.Cu   signals   (rev B: the camera took the back layer the router
#   In3.Cu   signals    had for the RP2350's fan-out; these give it back)
#   In4.Cu   the supplies, directly over the back layer
#   B.Cu     signals, the camera's wiring and its parts
COPPER = ["F.Cu", "In1.Cu", "In2.Cu", "In3.Cu", "In4.Cu", "B.Cu"]
LAYER_IDS = {"F.Cu": 0, "B.Cu": 2, "In1.Cu": 4, "In2.Cu": 6, "In3.Cu": 8, "In4.Cu": 10}
LAYER_TYPE = {"F.Cu": "signal", "In1.Cu": "power", "In2.Cu": "signal", "In3.Cu": "signal",
              "In4.Cu": "power", "B.Cu": "signal"}
PREPREG, CORE, PREPREG_MID, CU_OUT, CU_IN, MASK = 0.2104, 0.4, 0.2028, 0.035, 0.0152, 0.01
USER_LAYERS = '''		(9 "F.Adhes" user "F.Adhesive")
		(11 "B.Adhes" user "B.Adhesive")
		(13 "F.Paste" user)
		(15 "B.Paste" user)
		(5 "F.SilkS" user "F.Silkscreen")
		(7 "B.SilkS" user "B.Silkscreen")
		(1 "F.Mask" user)
		(3 "B.Mask" user)
		(17 "Dwgs.User" user "User.Drawings")
		(19 "Cmts.User" user "User.Comments")
		(21 "Eco1.User" user "User.Eco1")
		(23 "Eco2.User" user "User.Eco2")
		(25 "Edge.Cuts" user)
		(27 "Margin" user)
		(31 "F.CrtYd" user "F.Courtyard")
		(29 "B.CrtYd" user "B.Courtyard")
		(35 "F.Fab" user)
		(33 "B.Fab" user)'''

def stackup():
    out = ['\t\t(stackup',
           '\t\t\t(layer "F.SilkS" (type "Top Silk Screen"))',
           '\t\t\t(layer "F.Paste" (type "Top Solder Paste"))',
           f'\t\t\t(layer "F.Mask" (type "Top Solder Mask") (thickness {MASK}))']
    diel = [("prepreg", PREPREG), ("core", CORE), ("prepreg", PREPREG_MID), ("core", CORE),
            ("prepreg", PREPREG)]
    for i, cu in enumerate(COPPER):
        th = CU_OUT if cu in ("F.Cu", "B.Cu") else CU_IN
        out.append(f'\t\t\t(layer "{cu}" (type "copper") (thickness {th}))')
        if i < len(diel):
            kind, t = diel[i]
            out.append(f'\t\t\t(layer "dielectric {i + 1}" (type "{kind}") (thickness {t}) '
                       f'(material "FR4") (epsilon_r 4.4) (loss_tangent 0.02))')
    out += [f'\t\t\t(layer "B.Mask" (type "Bottom Solder Mask") (thickness {MASK}))',
            '\t\t\t(layer "B.Paste" (type "Bottom Solder Paste"))',
            '\t\t\t(layer "B.SilkS" (type "Bottom Silk Screen"))',
            '\t\t\t(copper_finish "ENIG")',
            '\t\t\t(dielectric_constraints no)',
            '\t\t)']
    return "\n".join(out)

def skeleton():
    """An empty board with the layers, the stack and the title block: the
    part of a board file pcbnew's API does not write."""
    o = ['(kicad_pcb', '\t(version 20241229)', '\t(generator "pcbnew")',
         '\t(generator_version "9.0")',
         '\t(general (thickness 1.6) (legacy_teardrops no))', '\t(paper "A4")',
         f'\t(title_block (title "{TITLE}") (date "{DATE}") (rev "{REV}")\n'
         f'\t\t(company "Sequoia Hope Alexander")\n'
         f'\t\t(comment 1 "Generated by tools/gen_board.py from tools/circuit.py and tools/placement.py")\n'
         f'\t\t(comment 2 "CERN-OHL-P"))',
         '\t(layers']
    for cu in COPPER:
        o.append(f'\t\t({LAYER_IDS[cu]} "{cu}" {LAYER_TYPE[cu]})')
    o += [USER_LAYERS, '\t)', '\t(setup', stackup(),
          '\t\t(pad_to_mask_clearance 0)',
          '\t\t(allow_soldermask_bridges_in_footprints yes)',
          '\t\t(tenting front back)',
          f'\t\t(aux_axis_origin {OX} {OY})', f'\t\t(grid_origin {OX} {OY})',
          '\t)', '\t(net 0 "")', '\t(embedded_fonts no)', ')']
    return "\n".join(o) + "\n"
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

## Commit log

2026-10-02 comms rev A: RP2350A + ST60A3H1 60 GHz link board, generators, routed board, schematic, viewer
    Netlist, placement, board generator and router wrapper in tools/; the KiCad
    project in hardware/comms (78 parts, 80 nets, 0 unconnected, DRC and ERC
    clean, schematic netlist matches circuit.py); pcbview viewer on index.html.
    [01_mcu.kicad_sch, 02_link.kicad_sch, 03_usb_power.kicad_sch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]
2026-10-02 Schematic tidy-up, rebuilt viewer, GitHub Pages link
    Sheets re-laid for legibility (header pins as global labels, blocks
    spaced out); viewer rebuilt from the current sheets. .nojekyll so Pages
    serves the tree as it stands; README links the published page.
    [01_mcu.kicad_sch, 02_link.kicad_sch, 03_usb_power.kicad_sch]
2026-10-02 Rev A close-out: LCSC numbers, assembly sidecar, regen script
    hardware/parts/lcsc.csv gives every placed part an LCSC number, looked
    up in JLCPCB's library on 2026-10-02, and pcbview shows them in the
    part pane. tools/assembly.py exports IPC-2581, writes the boardvis
    sidecar (pin-1 evidence per polarised part) and runs boardvis: 0 errors.
    tools/regen.py runs DRC, ERC, the netlist comparison and boardvis, then
    rebuilds the viewer and the page's status line. Mounting holes are out
    of the BOM on the sheets, as their footprints say. Viewer rebuilt.
    [01_mcu.kicad_sch, lcsc.csv]
2026-10-02 Rev A after review: ST's antenna ground, 1.8 V rail, pull-ups, 90 ohm pairs
    Two independent reviews (schematic against the data sheets, layout
    against JLCPCB's limits and ST's B2379A) found no blocker and a dozen
    things worth fixing. The board is regenerated and routed again.
    Layout: the ST60's ball field is laid as ST lays it -- nine signals
    straight out through one side of the ring, the supply along the top --
    and the island and fence vias are ST's own, from its drill file (33 and
    45 fit, where rev A had 13 and 15). USB pairs on the back 0.28/0.16 mm;
    the +1V8 plane redrawn so the pair to the repeater has +3V3 under it
    throughout. ST60 mask openings 0.30 mm. Silkscreen to JLCPCB's sizes.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
    [01_mcu.kicad_sch, 02_link.kicad_sch, 03_usb_power.kicad_sch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]
2026-10-02 Rev B: OV2640 camera connector on the back, six layers
    A 24-way flex connector (FH12-24S-0.5SH) for the common OV2640 module,
    on the back of the board so the lens looks away from the link partner,
    with 2.8 V and 1.3 V regulators, pull-ups and decoupling. The camera's
    signals are header GPIO (0-7 data, 21 VSYNC, 22/23 SCCB, 24 PWDN,
    26 HREF, 27 XCLK, 28 PCLK), wired by hand on the back from the headers'
    own pads to the connector, none crossing.
    Six layers (JLC06161H-7628, same outer prepreg as the four-layer stack):
    with the back layer taken the board would not route on four. Parts on
    the back keep their vias out of the RP2350's fan-out gaps.
    An independent check confirmed the connector's p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
    [01_mcu.kicad_sch, 02_link.kicad_sch, 03_usb_power.kicad_sch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]
2026-11-09 Remove personal paths and hostnames from code and docs
    Sibling-repo paths now resolve beside the checkout (overridable with
    SERVODRIVE_DIR / RPI_REF_DIR); the freerouting jar comes from
    FREEROUTING_JAR or ~/Software/magnet/route.
